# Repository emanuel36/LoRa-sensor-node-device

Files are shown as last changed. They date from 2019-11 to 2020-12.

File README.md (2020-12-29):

  <h3 align="center">A low cost and low power LoRa device sensor-node</h3>

[][release-url]
[][commits-url]
[][stars-url]


 
 <p align="center">
    <br />
    <a href="https://github.com/emanuel36/LoRa-sensor-node-device//tree/master/documentation"><strong>:page_facing_up: Explore the documentation :page_facing_up:</strong></a>
    <br />
    <a href="https://github.com/emanuel36/LoRa-sensor-node-device/issues">:warning: Report or Suggest Something :warning:</a>
  </p>
</p>

<br />
<p align="center">
  <a href="https://github.com/emanuel36/LoRa-sensor-node-device/">
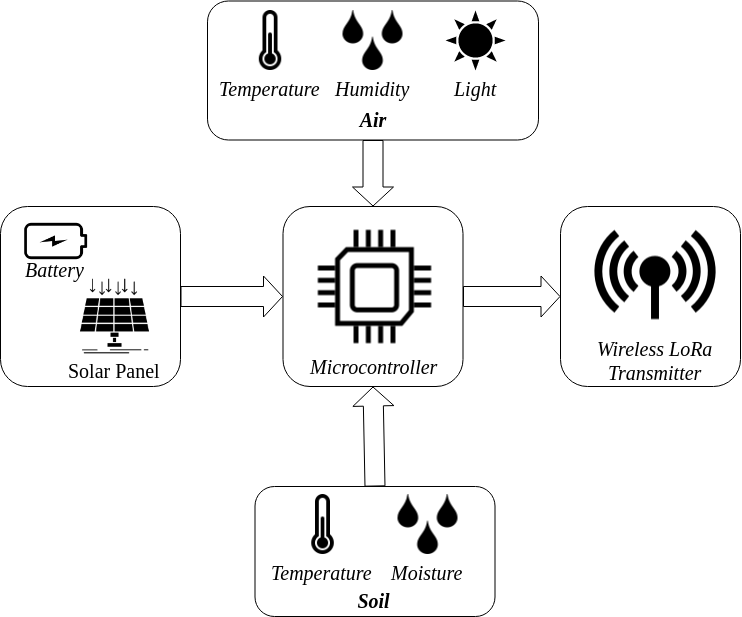
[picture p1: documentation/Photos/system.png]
System Architecture
    
    </a>

## Table of Contents

* [About the Project](#about-the-project)
  * [Built With](#built-with)
* [Detailed description](#detailed-description)
  * [Components Specifications](#components-specifications)
  * [Schematic](#schematic)
  * [Board](#board) 
* [Assembled Board With Components](#assembled-board-with-components)
* [Contact](#contact)

## About The Project

This is a project of a new LoRa device sensor-node. This device is capable of collecting environment data such as temperature, humidity, soil moisture and ambient as well as sending all data to a LoRa gateway from miles away. As can be seen from the [component specifications](#components-specifications) table, this device is very inexpensive, therefore it is suitable equipment to apply to a wireless sensor network in an agricultural field.

More details can be seen in this [publication](https://www.embarcados.com.br/dispositivo-sensor-no-lora-de-baixo-custo-utilizando-energia-solar/) (Portuguese language).

### Built With
* [LoRa](https://lora-alliance.org/)
* [PIC16F18426](https://www.microchip.com/wwwproducts/en/PIC16F18426)
* [MPLAP X IDE](https://www.microchip.com/mplab/mplab-x-ide)

### IDE and Compiler Version
* [MPLAB XC8 v2.10](https://www.microchip.com/development-tools/pic-and-dspic-downloads-archive)
* [MPLAP X IDE v5.30](https://www.microchip.com/development-tools/pic-and-dspic-downloads-archive)

## Detailed Description
This device is designed to work automatically without any human intervention. 

### Microcontroller
The PIC16F18426 is perfect for the project, it's a family of Microchip MCUs intended to sensor node devices.

### Sensors
The device has 4 sensors to measure air temperature, ground temperature, air humidity, soil moisture and sunlight or light levels.

### LoRa Transmitter
The cheap SX1276 transmitter works well at a frequency of 915 MHz, because I'm using it in Brazil.

### Power Supply System
The electrical and power system is designed for decades of operation, with a combination of a large rechargeable battery and a solar-powered recharge system. It is possible to use this device only with solar energy without battery, the battery is only for power supply when there is no sunlight, such as at night and cloudy days.

### Power-Saving Operation Mode
Most of the time the device remains in power save state with all peripherals turned off. When it is necessary to perform some task the system is woken up by an interruption. The data send and transmit period can be set between 5 and 80 minutes, so the system is woken up by a timer interrupt, performs the tasks and returns to power save mode.

### Status LED
The device can signal its current status through a flashing blue LED when it is operating normally and red when something is wrong such as low battery, sensor reading failure or incorrect sensor data such as 80ºC temperature.

### Components specifications

| Component | Description/Documentation | Price (USD) |
|---  |:---:  |---:  |
| Microcontroller | [PIC16F18426](https://www.microchip.com/wwwproducts/en/PIC16F18426) | $1,02 |
| LoRa Transmiter | [SX1276](https://www.semtech.com/products/wireless-rf/lora-transceivers/sx1276) | $4,15 |
| Solar Panel | [Wavgat solar panel 1W/5V](https://pt.aliexpress.com/item/32844672794.html?isOrigTitle=true)  | $1,31 |
| LED | [RGB LED](https://www.sparkfun.com/datasheets/Components/YSL-R596CR3G4B5C-C10.pdf)  | $0,10 |
| Voltage regulator | [LM2596](http://www.ti.com/product/LM2596)  | $0,30 |
| Switch | [DIP Switch 1 way](https://www.we-online.de/katalog/datasheet/418117270901.pdf)  | $0,16 |
| PINS | [Header pin male](https://cdn.sparkfun.com/datasheets/Prototyping/16188.pdf)  | $0,20  |
| MCU Socket | [14-PIN PDIP Socket](https://www.sparkfun.com/products/7939)  | $0,50 |
| 10k Resistors  | [10k Resistors](https://www.circuitspecialists.com/rb10k.html) | $0,12 |
| 4.7k Resistor  | [4.7k Resistors](https://www.circuitspecialists.com/ra4.7k.html) | $0,05 |
| Battery | [Panasonic NCR18650B](https://www.batteryspace.com/prod-specs/NCR18650B.pdf)  | $4,75 |
| Battery Holder  | [BK-18650-PC2](http://www.memoryprotectiondevices.com/datasheets/BK-18650-PC2-datasheet.pdf)  | $0,49 |
| Light Sensor  | [MAX44009](https://www.maximintegrated.com/en/products/interface/sensor-interface/MAX44009.html)  | $1,55 |
| Air Temperature/Humidity Sensor | [Sensirion SHT30](https://www.sensirion.com/en/environmental-sensors/humidity-sensors/digital-humidity-sensors-for-various-applications/) | $1,90 |
| Soil Moisture Sensor  | [Capacitive soil moisture sensor v1.2](https://media.digikey.com/pdf/Data%20Sheets/DFRobot%20PDFs/SEN0193_Web.pdf)  | $0,76 |
| Soil Temperature  | [DS18B20](https://www.maximintegrated.com/en/products/DS18B20)  | $1,00 |
|**Total** |-| **$18,36**|

### Schematic

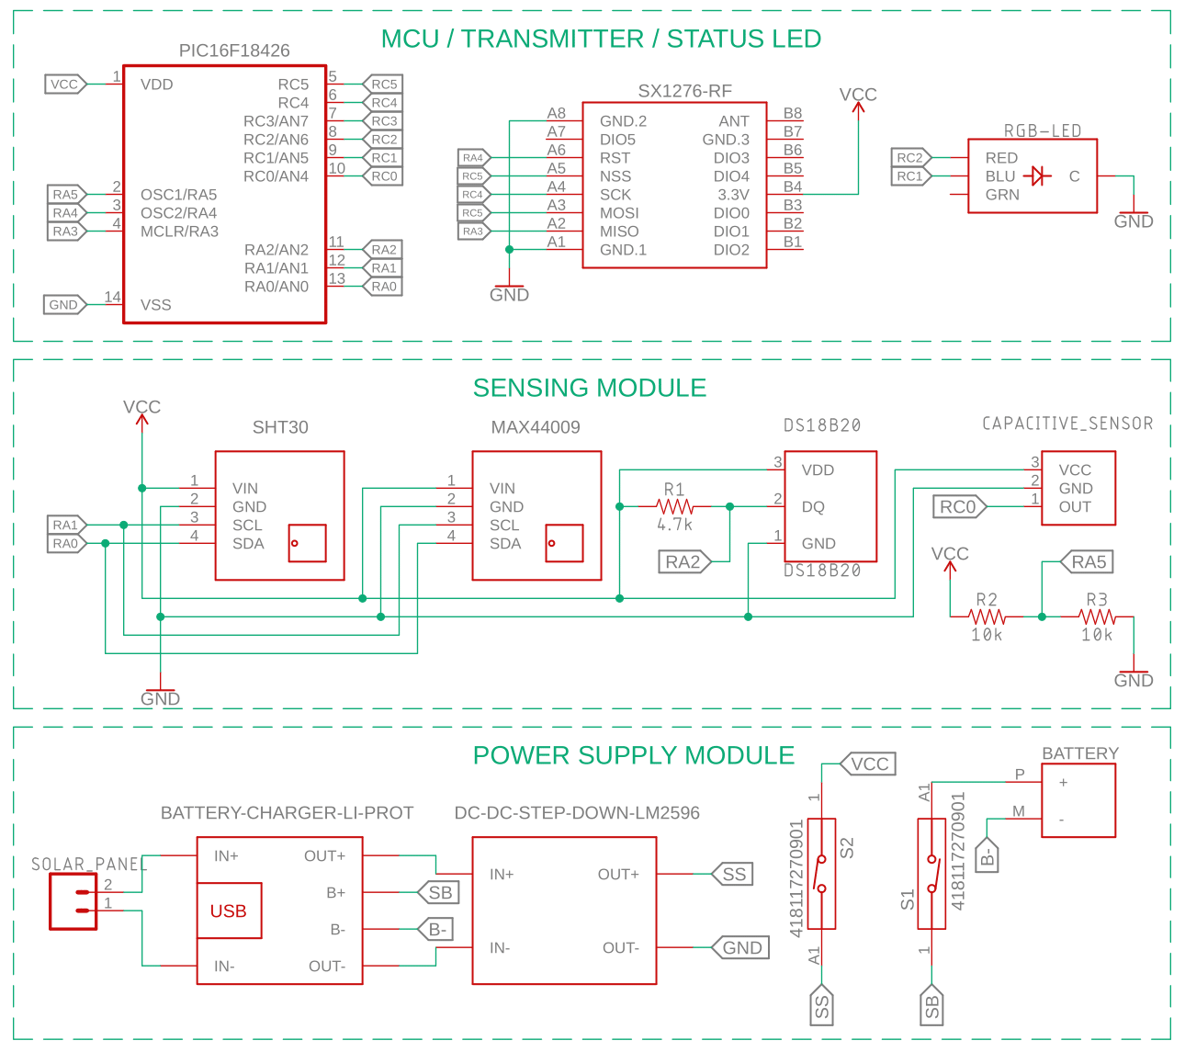
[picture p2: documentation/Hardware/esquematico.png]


### Board

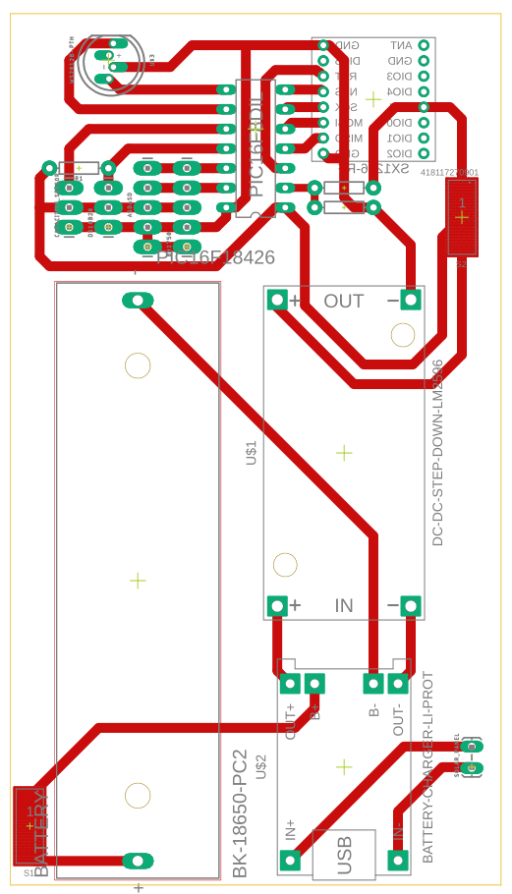
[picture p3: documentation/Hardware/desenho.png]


## Assembled Board With Components

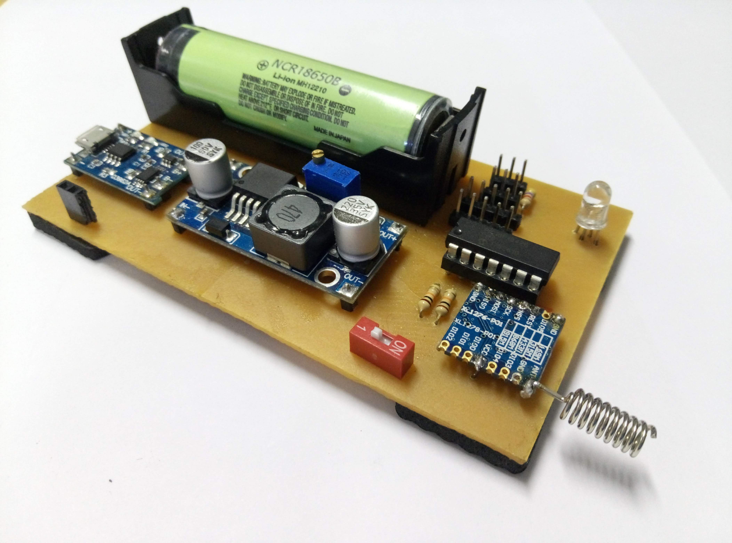
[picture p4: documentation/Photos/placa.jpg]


## System Running

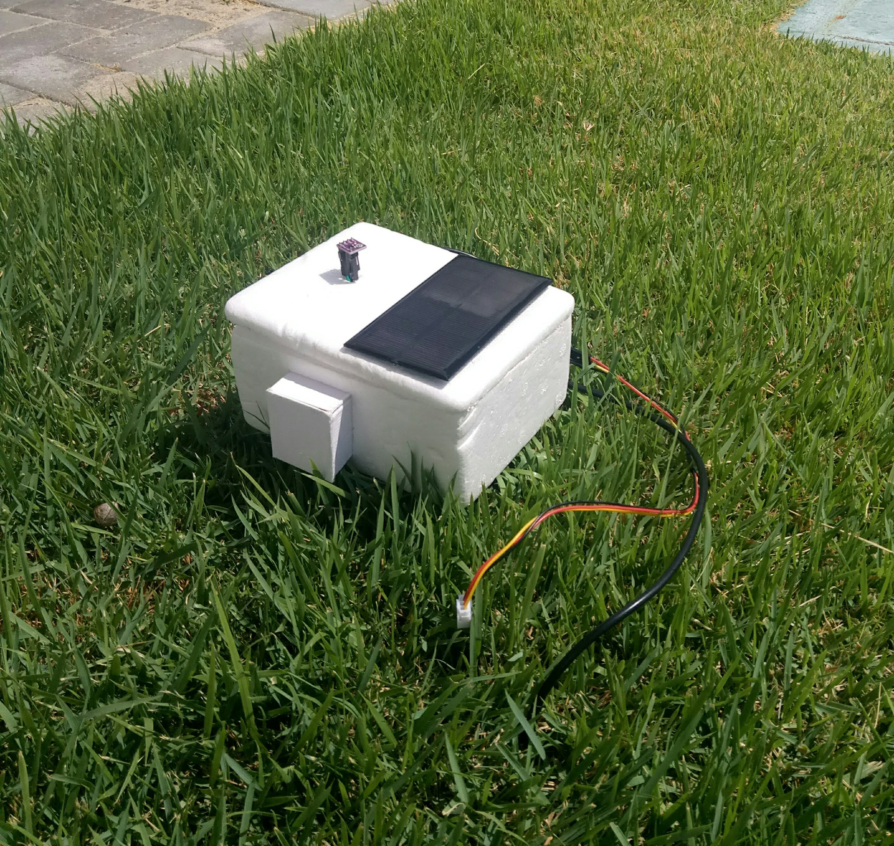
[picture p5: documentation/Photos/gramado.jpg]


## Data collected

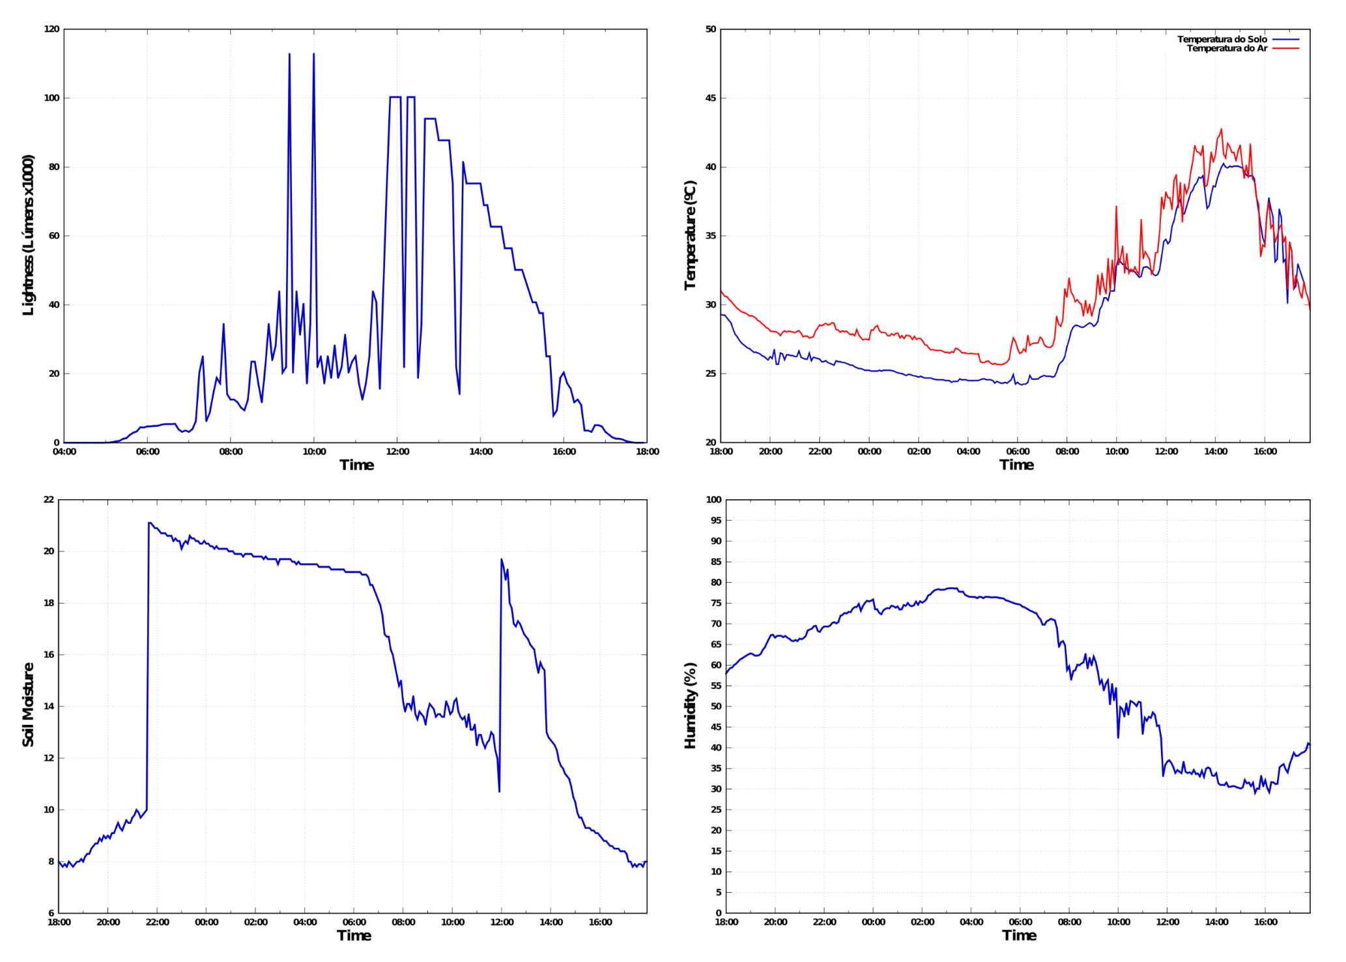
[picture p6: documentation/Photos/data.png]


## Acknowledgements

I would like to thank all the professors I've had since elementary school, this project is the result of a combination of everything you taught me.

The SX1276 LoRa transmitter driver was adapted from https://github.com/sandeepmistry/arduino-LoRa.

[contributors-shield]: https://img.shields.io/github/contributors/emanuel36/LoRa-sensor-node-device?style=for-the-badge
[commits-shield]:https://img.shields.io/github/last-commit/emanuel36/LoRa-sensor-node-device?style=for-the-badge
[commits-url]:https://github.com/emanuel36/LoRa-sensor-node-device/commits/master
[release-shield]:https://img.shields.io/github/v/release/emanuel36/LoRa-sensor-node-device?style=for-the-badge
[release-url]:https://github.com/emanuel36/LoRa-sensor-node-device/releases
[contributors-url]: https://github.com/emanuel36/LoRa-sensor-node-device/graphs/contributors
[stars-shield]: https://img.shields.io/github/stars/emanuel36/LoRa-sensor-node-device?color=183c0d&style=for-the-badge
[stars-url]: https://github.com/emanuel36/LoRa-sensor-node-device/stargazers
[language-shield]: https://img.shields.io/github/languages/top/emanuel36/LoRa-sensor-node-device?color=191970&style=for-the-badge
[language-url]: https://github.com/emanuel36/LoRa-sensor-node-device/search?l=c
[size-shield]: https://img.shields.io/github/languages/code-size/emanuel36/LoRa-sensor-node-device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
[issues-shield]: https://img.shields.io/github/issues/emanuel36/LoRa-sensor-node-device?style=for-the-badge
[issues-url]:https://github.com/emanuel36/LoRa-sensor-node-device/issues
[linkedin-shield]: https://img.shields.io/badge/-LinkedIn-blue?style=for-the-badge
[linkedin-url]: https://www.linkedin.com/in/emanuel36/en

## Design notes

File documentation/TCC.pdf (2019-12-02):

UNIVERSIDADE FEDERAL DO CEARÁ

CAMPUS DE QUIXADÁ

CURSO DE GRADUAÇÃO EM ENGENHARIA DE COMPUTAÇÃO

EMANUEL ANGELIM PEREIRA

IMPLEMENTAÇÃO DE UM DISPOSITIVO PARA REDE DE SENSORES SEM FIO

LORA ® UTILIZANDO ENERGIA SOLAR

QUIXADÁ - CEARÁ

2019

EMANUEL ANGELIM PEREIRA

IMPLEMENTAÇÃO DE UM DISPOSITIVO PARA REDE DE SENSORES SEM FIO LORA

® UTILIZANDO ENERGIA SOLAR

Trabalho de Conclusão de Curso apresentado ao Curso de Graduação em Engenharia de Computação do Campus de Quixadá da Universidade Federal do Ceará, como requisito parcial à obtenção do grau de bacharel em Engenharia de Computação.

Orientador: Prof. | Me. | Francisco Helder
Candido dos Santos Filho.

QUIXADÁ - CEARÁ

EMANUEL ANGELIM PEREIRA

IMPLEMENTAÇÃO DE UM DISPOSITIVO PARA REDE DE SENSORES SEM FIO LORA

® UTILIZANDO ENERGIA SOLAR

Trabalho de Conclusão de Curso apresentado ao Curso de Graduação em Engenharia de Computação do Campus de Quixadá da Universidade Federal do Ceará, como requisito parcial à obtenção do grau de bacharel em Engenharia de Computação.

Aprovada em:

BANCA EXAMINADORA

Prof. Me. Francisco Helder Candido dos Santos Filho. (Orientador)
Universidade Federal do Ceará (UFC)

Prof. Dr. André Ribeiro Braga Universidade Federal do Ceará (UFC)

Prof. Dr. Elvis Miguel Galeas Stancanelli Universidade Federal do Ceará (UFC)

Dedico esta monografia aos meus pais e avós,

pilares da minha formação como ser humano.

Palavras não são suficientes para demonstrar a

minha gratidão por sua dedicação, apoio, amor

e confiança em mim.

AGRADECIMENTOS

A minha mãe Edisônia, seus exemplos de vida, cuidado e carinho foi o que deu

sentido para continuar crescendo na vida e superando todos os desafios.

Ao meu Pai Marcelino, seu enorme apoio, presença e positividade significou espe-

rança, segurança e certeza de que não estou sozinho nessa caminhada.

Aos meus avós Carmelita, Maria e Mauro, que sempre sonharam em me ver formado

e se preocuparam comigo apoiando e confiando em mim.

Aos meus irmãos, tios e primos, por me apoiarem e estarem próximo de mim.

Ao Prof. Francisco Helder Candido dos Santos Filho por me orientar no meu

Trabalho de Conclusão de Curso.

Aos professores, por me repassar o seu conhecimento técnico e experiências de vida,

vocês foram essenciais nessa jornada.

Ao Prof. Alisson Barbosa de Souza por apoiar e sugerir o tema principal deste

trabalho.

A minha prima Débora Ferreira, por estar sempre comigo e por revisar a ortografia

do texto deste trabalho.

Ao Robert Cabral, pelo apoio durante toda execução do trabalho.

Ao meu amigo Túlio, por revisar todo o trabalho.

“O impossível existe até que alguém duvide dele

e prove o contrário.”

(Albert Einstein)

RESUMO

As Redes de Sensores sem Fio estão sendo utilizadas cada vez mais em diversos tipos de

sistemas voltados para monitoramento. Entre os protocolos de comunicação utilizados por esses

sistemas, o LoRa ® vem ganhando destaque devido suportar transmissões em distâncias muito

maiores que os demais, demandando pouca energia. Utilizar fontes de energias renováveis

como energia solar, também tem sido uma tendência, com o intuito principal de não agredir o

meio ambiente bem como tornar a aplicação do sistema mais barata a longo prazo. O presente

trabalho propõe o desenvolvimento de um dispositivo para atuar em uma rede de sensores sem

fio utilizando o protocolo LoRa ®, assim como energia solar como fonte de alimentação do

sistema. O dispositivo deverá dispor de alguns sensores de forma que o sistema seja voltado para

aplicações no campo, tornando processos como agricultura mais eficientes. Entre os resultados

há o detalhamento do processo de seleção de cada componente do dispositivo assim como

o comportamento de cada sensor durante um período de 24 horas de leituras e transmissões.

Além disso é apresentado as funcionalidades do dispositivo e as principais configurações dos

periféricos e módulos do microcontrolador.

Palavras-chave: LoRa. Microcontrolador. Redes de Sensores sem Fio. Sensor.

ABSTRACT

Wireless Sensor Networks are increasingly being used in various types of systems focused

on monitoring. Among the communication protocols used by these systems, LoRa ® has

gained prominence because it supports transmission over much longer distances than the others,

requiring little energy. Use renewable energy sources as energy solar, has also been a trend,

with the main purpose of not harming the environment as well as making the system application

cheaper in the long run. The present thesis proposes the development of a device to operate

in a wireless sensors network using LoRa ® protocol, as well as solar energy as a source of

system power. The device should have some sensors in such a way that the system be focused

on agriculture applications, improving the process. The results include a detailed process for

selecting each device component as well as the behavior of each sensor over a 24 hours of reading

and transmissing period. In addition, the device main features are shown as configurations of

microcontroller peripherals and modules.

Keywords: LoRa. Microcontroller. Wireless Sensor Network. Sensor.

LISTA DE FIGURAS

Figura 7 – Diagrama de bloco de um nó genérico de uma rede de sensores sem fio . . . | 29
Figura 8 – Corrente de alimentação dos transmissores LoRa ® SX1276 e RN2903 . . . | 36

LISTA DE TABELAS

LISTA DE QUADROS

LISTA DE CÓDIGOS-FONTE

Código-fonte 3 – Estrutura que contém os perídos configuráveis do temporizador . . . 44

LISTA DE SÍMBOLOS

km | Distância
km² | Área
kHz | Frequência
MHz | Frequência
GHz | Frequência
dBm | Potência
V | Tensão Elétrica
mA | Corrente elétrica
µA | Corrente elétrica
kΩ | Resistência Elétrica
MHz | Frequência
◦C | Temperatura
Lux | Luminosidade

SUMÁRIO

### 2.1 Development of Plough-able RFID Sensor Network Systems for Preci-

### 2.2 Design and implementation of WSN for precision agriculture in white

### 2.3 Monitoring device for culture substrate growth parameters for precision

4.2 | Definir protocolo de comunicação que será suportado pelo sistema . . . | 32

### 1 INTRODUÇÃO

Entre os maiores problemas e desafios enfrentados atualmente pela humanidade,

incluem-se: a falta de água própria para consumo, mudanças drásticas no clima e produção de

comida insuficiente, principalmente em regiões mais pobres (ILIE-ABLACHIM et al., 2016).

Na região Nordeste do Brasil muitos agricultores são bastantes limitados em relação ao período

do ano em que podem realizar o plantio em médias e grandes proporções, pois além da taxa

de precipitação ser muito baixa, toda essa precipitação ocorre durante um único e pequeno

período do ano. Dessa forma, durante o período de seca, o agricultor não consegue exercer seu

trabalho na lavoura pois a quantidade de água necessária para irrigar a plantação com os métodos

tradicionais é insuficiente.

A prática da agricultura convencional, que utiliza métodos tradicionais, é bastante

ineficiente, pois demanda uma elevada quantidade de recursos, incluindo água. A agricultura

no Brasil é responsável pelo maior consumo de água, cerca de 72% do consumo total (ALVES,

2015). Contudo, a produção pode ser otimizada de forma muito significativa, ao adotar técnicas

avançadas na agricultura. A aplicação da tecnologia no campo pode envolver conceitos que

surgiram e estão evoluindo ao longo dos últimos anos: Internet of Things (IoT), Wireless Sensor

Network (WSN) e Precision Agriculture (PA).

O conceito IoT se refere a ter diversos aparelhos conectados na Internet, sendo

acessíveis ou controláveis a partir de qualquer lugar e dispositivo que possua conexão à Internet.

Os sistemas WSN utilizam ondas de rádio para transmitir os pacotes coletados pelos dispositivos

finais, que por sua vez, são formados basicamente de sensores, microcontrolador, transmissor e

sistema de alimentação. E por fim, a PA consiste em utilizar tecnologia avançada para aumentar

a quantidade e a qualidade da produção utilizando menos recursos naturais.

Visando a problemática apresentada, o presente trabalho propõe uma solução que

utilizará os conceitos citados anteriormente: WSN, IoT e PA. O trabalho tem foco no desenvol-

vimento do projeto de um dispositivo que atuará como um nó em uma WSN. Este dispositivo

deverá ser capaz de realizar medidas de fatores ambientais, que influenciam na atividade da

agricultura. Além de processar os dados obtidos, o dispositivo final deverá suportar o envio das

informações para uma base de dados, que poderá reunir as informações atualizadas de todos os

nós conectados na rede. Com todos os dados reunidos e acessíveis, um sistema poderá acessar

esses dados que interferem na plantação, como umidade, temperatura e radiação solar. A partir

desses dados, sistemas de irrigação poderão controlar a quantidade de água em cada região do campo de forma muito precisa, e em ambientes mais controláveis, poderá ajustar os níveis de

luminosidade e umidade do ar de acordo com as necessidades do tipo de plantação.

Os trabalhos de Wang et al. (2014), Juan et al. (2017) e Ilie-Ablachim et al. (2016)

apresentam soluções similares, contudo, a maioria é voltada para um tipo específico de local

ou de plantação, pois possuem alguns tipos de limitações, tais como alcance de transmissão,

alto consumo de energia, baixa autonomia e baixa disponibilidade. O dispositivo proposto neste

trabalho deverá possuir alto nível de automatização e autonomia, de modo que seja possível a

aplicação do mesmo modelo de dispositivo em redes de sensores sem fio situadas em diversos

tipos de plantações e tipos de ambientes.

### 1.1 OBJETIVOS

### 1.1.1 Objetivo geral

Desenvolver um dispositivo para ser utilizado como um nó em uma WSN, de forma

que este dispositivo seja capaz de operar em conjunto com outros sistemas em busca de tornar o

processo da agricultura mais eficiente e econômico.

### 1.1.2 Objetivos Específicos

- Utilizar um protocolo de comunicação que suporte um transmissor de longo alcance, baixo

consumo de energia e fácil escalabilidade dentro da rede.

- Selecionar os componentes mais adequados ao projeto, levando em conta suas característi-

cas individualmente.

- Implementar um sistema fotovoltaico para alimentar o dispositivo e recarregar a bateria.
- Aplicar técnicas de minimização de consumo de energia, em busca de obter alta durabili-

dade e disponibilidade.

- Montar um protótipo com todos os componentes do sistema, submetê-lo a testes e analisar

os resultados obtidos.

### 2 TRABALHOS RELACIONADOS

Nesta seção serão apresentados três trabalhos relacionados, destacando seus pontos

fortes e pontos negativos além das semelhanças e diferenças com o dispositivo proposto por este

trabalho.

### 2.1 Development of Plough-able RFID Sensor Network Systems for Precision Agricul-

ture

A ideia geral do trabalho desenvolvido por Wang et al. (2014) é implementar um

dispositivo com sensores, microcontrolador, transmissor e antena. Sua proposta consiste em

espalhar vários dispositivos em um campo, que devem ficar sob o solo, em uma profundidade

adequada para realizar leituras de parâmetros e enviar os dados coletados para um instrumento

leitor que se posicionará sobre o solo.

O diferencial desse dispositivo é o protocolo de comunicação: o Radio Frequency

Identification (RFID). O sistema RFID passivo, que é o utilizado neste projeto, se destaca por

não necessitar de alimentação contínua. Isso ocorre devido ao transmissor que se localiza no

dispositivo final, que além de enviar dados para o leitor, alimenta o sistema através da corrente

induzida pelo campo magnético gerado pelo leitor (TANIM, 2016). Dessa forma, para coletar

informações de um determinado dispositivo, um equipamento leitor RFID deve ser posicionado

sobre a região do solo que se encontra o dispositivo, logo, o sistema será alimentado pelo campo

magnético do leitor, que por sua vez receberá os dados de leitura enviados pelo transmissor.

A grande vantagem desse sistema é o fato do seu módulo de alimentação não interferir

na sua a autonomia. Outra grande vantagem é o custo individual de cada dispositivo, pois o

sistema RFID passivo é muito barato (LI et al., 2018). Porém a necessidade de um leitor para

realizar as medições torna o sistema mais dependente da ação humana e menos automatizado.

Além disso, em plantações mais altas, o posicionamento do leitor seria um desafio, o que limita

a aplicação do modelo em plantações baixas.

Apesar de ter um objetivo em comum com o projeto proposto neste trabalho, existem

diversas diferenças entre os dois dispositivos. De uma forma geral, o modelo desenvolvido por

Wang et al. (2014) é voltado para coletar informações somente do solo, enquanto o proposto

neste trabalho será capaz de ler dados do solo e do ar. Outra grande diferença é o modo de

transmissão de dados, em Wang et al. (2014) é necessária atuação humana, no trabalho proposto, o processo é totalmente automatizado.

### 2.2 Design and implementation of WSN for precision agriculture in white cabbage crops

No trabalho de Juan et al. (2017), foi implementado um dispositivo chamado Smart-

Node, que possui três sensores que são responsáveis por coletar informações sobre luminosidade,

temperatura do ar e umidade do solo. O objetivo principal do seu trabalho é enviar informações

ambientais do local de uma plantação de repolho para um servidor localizado a uma distância de

aproximadamente 2 km do local onde os dispositivos estão instalados.

O sistema de alimentação desse dispositivo merece destaque, pois utiliza uma bateria

recarregável, e através de uma placa solar e um circuito de carregamento, essa bateria é recar-

regada utilizando energia renovável. Esse sistema gera economia, pois a bateria recarregável

dura muito mais tempo que uma comum, gera autonomia devido a desnecessidade de remover as

baterias para recarregar e não menos importante, minimiza o impacto ambiental já que evita o

descarte excessivo de baterias.

Entretanto, Juan et al. (2017) optou por utilizar o protocolo de comunicação Zigbee,

que transmite dados na frequência 2,4 GHz (PAN et al., 2018), um dos motivos que torna o

alcance de comunicação baixo. Além disso, o protocolo Zigbee utiliza o método de múltiplos

saltos, dessa forma outros nós presentes na rede precisam rotear pacotes de outros nós próximos

fisicamente (MEERA et al., 2015), o que aumenta a complexidade da rede e causa dependências.

Em outras palavras, caso um nó essencial no roteamento de pacotes fique indisponível, parte dos

nós perderão a conexão com a rede, comprometendo todo o sistema. Outro impacto negativo

causado pelo protocolo baseado em múltiplos saltos é o acréscimo do tempo ativo dos dispositivos,

visto que terão de ficar ativos sempre que tiverem de enviar seus próprios dados ou rotear pacotes

de outros nós, o que afeta diretamente o consumo de energia.

O objetivo final da pesquisa de Juan et al. (2017) possui grandes semelhanças com o

objetivo final do trabalho proposto. Ambos tem intenção de otimizar o processo da agricultura

através da coleta e envio de informações ambientais, além de utilizarem energia renovável como

fonte de alimentação. Contudo, o dispositivo de Juan et al. (2017) é voltado para plantações

rasteiras, como as de repolho, enquanto o dispositivo proposto poderá ser aplicado em diversos

tipos de plantações. Além disso, o protocolo de comunicação do SmartNode limita bastante a

distância entre os dispositivos da rede, portanto, a implementação de um sistema em um campo

extenso utilizando esse modelo terá um alto custo, devido a quantidade de dispositivos necessária.

### 2.3 Monitoring device for culture substrate growth parameters for precision agriculture

No trabalho desenvolvido por Ilie-Ablachim et al. (2016) foi projetado um dispositivo

nomeado MoniSen. O MoniSen é um modelo de dispositivo final que pode ser aplicado em uma

rede de sensores sem fio de longo alcance, pois utiliza o protocolo de comunicação LoRa ® que

tem como características principais o longo alcance de transmissão e o baixo consumo de energia

(DEVALAL; KARTHIKEYAN, 2018).

O dispositivo em si é composto por alguns sensores que são responsáveis por medir

os seguintes parâmetros: luminosidade, temperatura do solo, temperatura do ar, umidade do

solo e umidade do ar. Os modelos de sensores selecionados para o projeto não são os melhores,

pois existem opções mais precisas, econômicas e com custo de aquisição similar. Além desses

sensores, o MoniSen possui o transmissor LoRa ® e um microcontrolador de baixo processamento

e consumo. As baterias de lítio que o alimenta tem capacidade de 2400 mAh, dando uma

autonomia de aproximadamente 6 meses.

O projeto desenvolvido por Ilie-Ablachim et al. (2016) é similar ao projeto proposto

neste trabalho, pois ambos utilizam sensores para medir parâmetros do ar e do solo do ambiente,

além de possuírem suporte a transmissão de longo alcance. As diferenças mais impactantes entre

os dois modelos são a qualidade dos sensores e o sistema de alimentação, tendo em vista que

o modelo proposto neste trabalho utiliza energia solar para recarregar a bateria. Uma grande

vantagem de implementar um sistema de alimentação mais robusto é a capacidade de realizar

leituras e envios dos dados com uma maior frequência, o que torna possível uma análise mais

detalhada sobre o comportamento do ambiente.

### 2.4 Análise comparativa

No Quadro 1, há a comparação entre os dispositivos projetados nos trabalhos rela-

cionados e o dispositivo projetado neste trabalho, mostrando as funcionalidades que cada um

possui.

Quadro 1 – Comparação entre os trabalhos relacionados e o proposto
Funcionalidade | Modelos de dispositivo
2.1 Sistema RFID | 2.3 MoniSen | 2.2 SmartNode | Trabalho proposto
Suporte à comunicação de longo alcance | ✗ | ✓ | ✗ | ✓
Autonomia elétrica ilimitada | ✓ | ✗ | ✓ | ✓
Sistema fotovoltaico de alimentação | Não se aplica | ✗ | ✓ | ✓
Ecologicamente sustentável | ✓ | ✗ | ✓ | ✓
Sensor de umidade do ar | ✗ | ✓ | ✓ | ✓
Sensor de temperatura do ar | ✗ | ✓ | ✓ | ✓
Sensor de umidade do solo | ✓ | ✓ | ✓ | ✓
Sensor de temperatura do solo | ✓ | ✓ | ✓ | ✓
Sensor de luminosidade | ✗ | ✓ | ✗ | ✓

Fonte: Elaborado pelo autor.

Como pode ser observado, o sistema proposto por Juan et al. (2017) é o que mais

se aproxima do sistema proposto nesse trabalho, contudo não suporta comunicação de longo

alcance, nem é capaz de medir os níveis de luminosidade do ambiente. O fato do dispositivo

proposto suportar todas essas funcionalidades, o torna capaz de atuar em diferentes tipos de

ambientes e plantações.

### 3 FUNDAMENTAÇÃO TEÓRICA

### 3.1 Sensores

Um sensor é um dispositivo capaz de responder a um estímulo físico ou químico

e converter em outra grandeza física, em busca de obter medidas ou realizar monitoramento

(BALBINOT; BRUSAMARELLO, 2011). Os sensores possuem um componente denominado

transdutor, que é responsável por converter o sinal proveniente da interação entre o sensor e o

ambiente físico em um sinal elétrico analógico ou digital. A partir do sinal elétrico, um sistema

pode realizar a leitura do sensor a fim de obter a informação fornecida pelo mesmo (BOARD et

al., 1997). A Figura 1 fornece uma visão geral da estrutura básica de um sensor genérico.

Figura 1 – Modelo genérico de um sensor

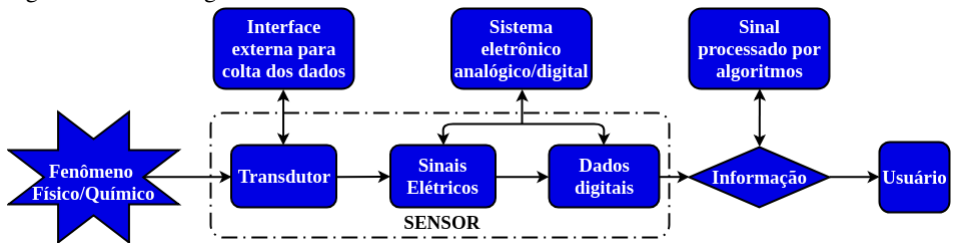
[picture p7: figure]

Fonte: Adaptado de Board et al. (1997)

Os sensores são bastante utilizados na indústria, e tem uma grande contribuição nos

recentes avanços tecnológicos, pois os sistemas de carros, aviões, satélites, computadores, e até

mesmo de aparelhos mais simples como condicionador de ar, possuem sistemas de controle.

Os sensores são componentes cruciais para o funcionamento desse tipo de sistema, visto que a

atuação e comportamento do sistema depende do estado do ambiente, que é obtido a partir da

leitura dos seus sensores. A Figura 2 mostra alguns modelos de sensores comumente utilizados

em projetos de sistemas de controle e monitoramento.

Alguns fatores ambientais interferem diretamente no desenvolvimento da plantação,

tais como temperatura, umidade e luminosidade. Em busca de realizar medições automatizadas

desses fatores, o dispositivo proposto neste trabalho terá alguns sensores como componentes

cruciais.

Figura 2 – Modelos de sensores

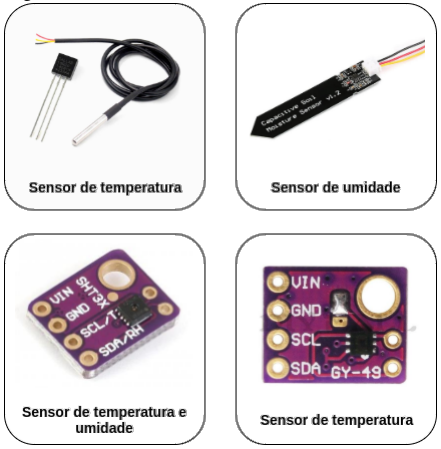
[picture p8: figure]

Fonte: Elaborado pelo autor.

### 3.2 Rede de sensores sem fio

Diferentemente de uma rede cabeada, as redes sem fio proporcionam uma grande

mobilidade dos dispositivos nela conectados. Ao invés de se propagar através de sinais elétricos

em cabos, os dados trocados entre dispositivos dentro da rede, se propagam por meio de ondas

de rádio. O uso de uma rede sem fio permite evitar meios dispendiosos de instalar cabos para

conectar dispositivos em diferentes locais (TIWARI et al., 2015).

De acordo com a autora Forster (2016) um sistema WSN é um termo que especifica

um conjunto de computadores com o objetivo principal de medir alguma propriedade física do

ambiente como temperatura, umidade ou vibração. Um sistema WSN é composto por vários

dispositivos com sensores acoplados, que realizam a função de um nó na rede, além disso,

esses dispositivos são conectados em uma rede através de tecnologias de comunicação sem fio.

Tipicamente, há um dispositivo especial na rede, que é chamado de estação base, o qual conecta

a rede de sensores ao mundo exterior.

Figura 3 – Exemplo de rede Rede de Sensores sem Fio

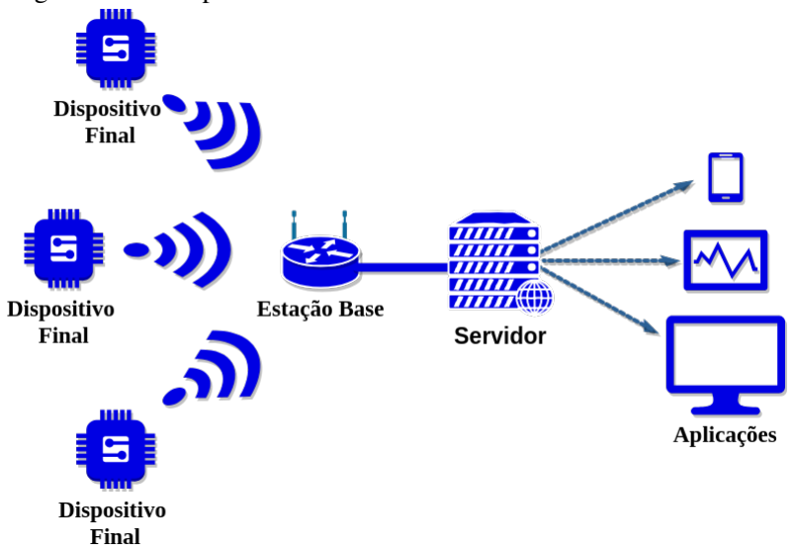
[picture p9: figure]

Fonte: Elaborado pelo autor.

A Figura 3 dá uma visão geral da estrutura básica de uma rede WSN. Como pode

ser observado, cada dispositivo final é capaz de enviar e receber da estação base, utilizando um

protocolo de comunicação sem fio. A estação base encaminha esses dados para um servidor, que

disponibiliza os dados para os usuários, através de aplicações.

### 3.2.1 Desafios em redes de sensores sem fio

O autor Tiwari et al. (2015) lista alguns desafios relacionados ao desenvolvimento

de WSN.

1. Segurança: Os pacotes trocados entre os nós da rede podem ser interceptados, já que são

transmitidos através de ondas de rádio.

2. Localização: A localização geográfica dos nós além de afetar o consumo de energia,

interfere na arquitetura de rede de protocolos de roteamento indireto.

3. Consumo de energia e autonomia: Em diversos sistemas de WSN os nós são posiciona-

dos em áreas de difícil acesso, dessa forma a necessidade de trocas frequentes de bateria

pode não ser viável, logo o consumo do dispositivo deve se minimizado ao máximo.

### 3.2.2 Protocolos mais utilizados em redes de sensores sem fio

3.2.2.1 LoRa ®

Segundo o trabalho de Devalal e Karthikeyan (2018), o protocolo LoRa ® é voltado

para sistemas que utilizam baterias e precisam transmitir pequena quantidade de dados em

intervalos curtos e em longas distâncias. Os transmissores LoRa ® utilizam faixas de frequências

que podem variar de acordo com a região. A Tabela 1 especifica as faixas de frequências

utilizadas em diferentes regiões do globo terrestre.

Tabela 1 – Banda de frequência por região

Região | Banda
Europa | 868 e 433 MHz
América do norte e Brasil | 915 MHz
Ásia | 430 MHz

Fonte: Adaptado de LoRa Alliance Technical Commitee (2017)

A arquitetura da rede LoRa ® é baseada na topologia estrela, na qual um dispositivo

central, o roteador recebe e envia dados para os dispositivos finais da rede. O roteador deve ser

conectado à Internet através de Wi-Fi, Ethernet, rede de celular ou satélite, visando enviar os

dados recebidos dos dispositivos finais para uma base de dados. Em uma rede LoRa ® pode

existir mais de um roteador, caso apenas um não seja suficiente para cobrir uma determinada

área. Esses dispositivos possuem um alcance muito grande, os mais robustos conseguem cobrir

uma área de até 100 km²
(DEVALAL; KARTHIKEYAN, 2018).
Region | Frequency
Europe | 868/433 MHz
America | 915 MHz
Asia | 430 MHz

3.2.2.2 Zigbee

O protocolo Zigbee é voltado para aplicações de curto e médio alcance que variam

entre 10 e 100 metros de distância (FARAHANI, 2009). Os dispositivos que compõe uma

rede Zigbee são os dispositivos finais, os roteadores e o coordenador de rede. De acordo com

a organização desses dispositivos na rede, o protocolo pode assumir três tipos diferentes de

topologias, que podem ser observadas na Figura 4.

- Estrela

Na topologia estrela, o coordenador pode se comunicar com qualquer outro dispositivo

conectado na rede.

- Malha

Na topologia malha, um dispositivo pode se comunicar com qualquer outro na rede,

desde que a distância entre os dois seja suficientemente pequena a ponto de permitir troca

de mensagens. Essa configuração permite que existam múltiplos caminhos ligando um

dispositivo aos outros na rede.

- Árvore

Essa topologia se assemelha à topologia malha, entretanto nesse modo de operação os

dispositivos finais não realizam roteamento de pacotes, apenas o roteadores e o coordenador

assumem esse papel.

Figura 4 – Topologias de uma rede Zigbee

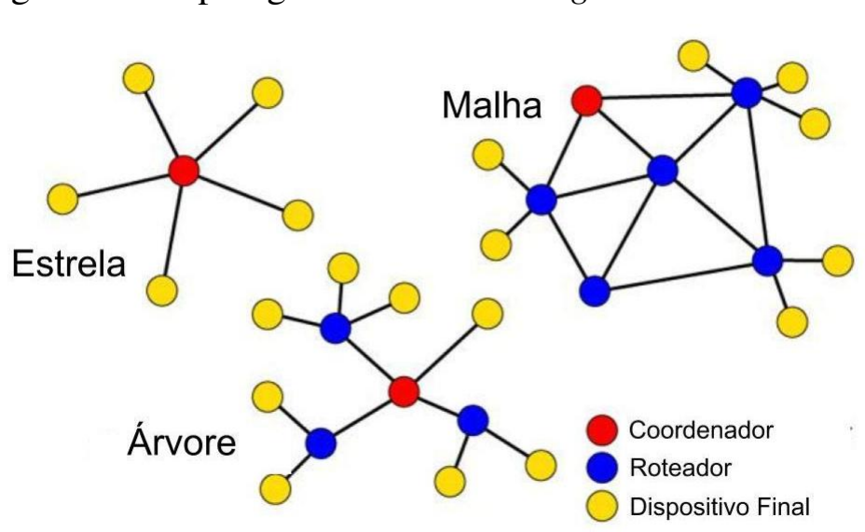
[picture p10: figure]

Fonte: Adaptado de Pathak et al. (2015)

As aplicações mais comuns que utilizam o Zigbee como protocolo de transmissão

são em automação residencial e comercial, controle industrial, monitoramento de parâmetros

relacionados à saúde pessoal, entre outras (TOMAR, 2011).

3.2.2.3 Wi-Fi

O protocolo IEEE 802.11, popularmente conhecido como Wi-Fi também pode ser

aplicado em WSN. Contudo, este protocolo não foi desenvolvido especificamente para este fim,

logo pode ser inviável utilizá-lo, dependendo dos requisitos do sistema.

Este protocolo possui dois modos de operação: infraestruturado e ad hoc, como

pode ser observado na Figura 5. O modo infraestruturado consiste em uma topologia estrela, na

qual um dispositivo central se conecta com todos os outros dispositivos, já no modo ad hoc, os

dispositivos se comunicam diretamente entre si, com diferentes possibilidades de roteamento das

mensagens enviadas (ANASTASI et al., 2003).

Figura 5 – Modos de operação da rede Wi-Fi

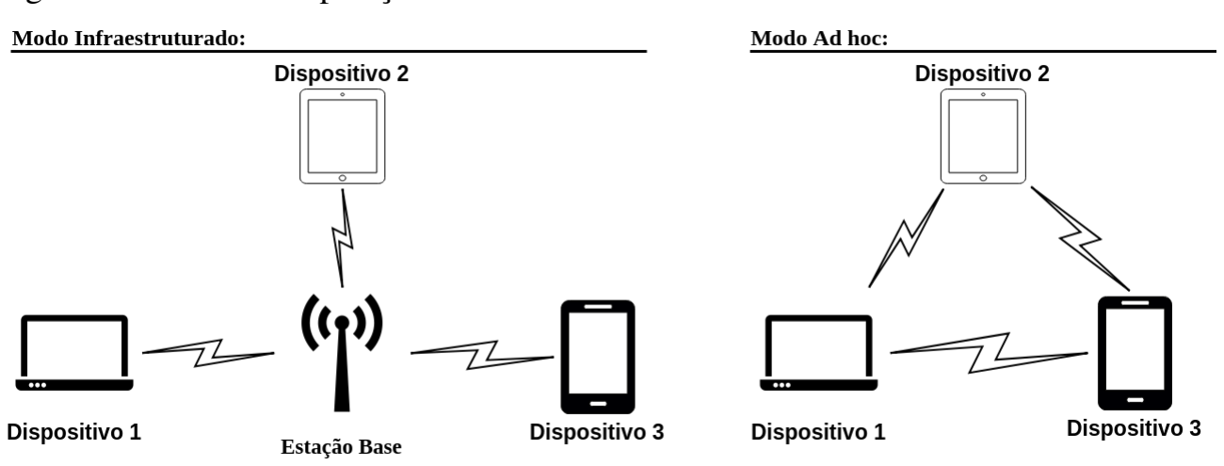
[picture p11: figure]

Fonte: Elaborado pelo autor.

O grande desafio de utilizar Wi-Fi em redes de sensores é o consumo de energia

do transmissor. Um transmissor Wi-Fi muito comum em projetos, o ESP-01 (AI-THINKER,

2015), possui um consumo muito maior, se comparado com um transmissor LoRa ® SX1276

(SEMTECH, 2015), como pode ser observado no gráfico da Figura 6.

### 3.2.3 Estrutura básica de um nó em uma rede de sensores sem fio

Cada nó de uma WSN é composto basicamente por microcontrolador, sensores,

bateria e transmissor, como demonstra a Figura 7. Com a possibilidade de aplicar sistemas

de WSN em grandes áreas para monitoramento, cada nó deve ser barato. Em busca de tornar

esses dispositivos baratos, os recursos presentes em cada dispositivo são altamente limitados, em

relação a processamento, energia e componentes de hardware (FORSTER, 2016) .

O propósito principal deste trabalho é desenvolver um modelo de nó voltado para

Figura 6 – Consumo dos transmissores LoRa ® SX1276 e Wi-Fi ESP-01

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
8 | 10 | 12 | 14 | 16

Consumo (mA)

Potência (dBm)

SX1276
ESP−01

Fonte: Elaborado pelo autor.

Figura 7 – Diagrama de bloco de um nó genérico de uma rede de sensores sem fio

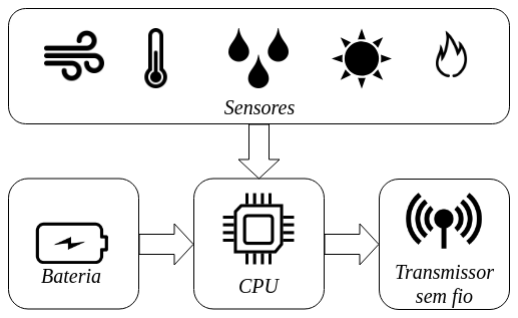
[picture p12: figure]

Fonte: Elaborado pelo autor.

monitoramento no setor da agricultura, em busca de torná-la mais eficiente e econômica.

Quadro 2 – Aplicações de redes de sensores sem fio
Área | Aplicação
Industrial | Monitoramento e controle de equipamentos
Aeroportos | Sistema de etiquetas inteligente em malas
Comercial | Gerência de estoque e check out
Situações emergenciais | Detectores de incêndio e vazamento de gás
Militar | Detectação de movimentação inimiga
Fonte: Adaptado de García-Hernández et al. (2007)

O Quadro 2 mostra algumas das diversas outras aplicações de sistemas WSN.

### 3.3 Agricultura de Precisão

De acordo com o autor Davis et al. (1998), a PA combina as novas tecnologias da

era da informação com a agricultura industrializada. Um sistema baseado em PA visa descobrir

as necessidades reais de insumo em pequenas áreas dentro de um campo agrícola, de modo

que a aplicação desses recursos não seja excedente ou insuficiente, mas seja suficiente para o

desenvolvimento da plantação. Esse propósito não é novo, entretanto as tecnologias recentes

permitem o avanço na pesquisa e desenvolvimento de sistemas nessa área.

O fator chave para a PA ser mais eficiente que a agricultura tradicional é a informação.

A forma com que a informação é coletada é essencial para a eficiência dos sistemas de PA, pois

nesses sistemas, o campo agrícola é dividido em pequenas áreas, visto que cada área pode ter

necessidades diferentes de insumo, de acordo com o relevo, tipo de solo, tempo de exposição

ao sol, temperatura e umidade. Em um terreno muito grande, essa necessidade de divisão em

pequenas áreas fica mais visível, pois as características ambientais podem variar muito entre

regiões situadas a algumas centenas de metros entre si (DAVIS et al., 1998).

Baseado nas condições ambientais de pequenas áreas divididas dentro do campo

agrícola, a aplicação de insumos pode ser precisamente controlada em cada uma dessas áreas de

forma independente, o que gera uma série de benefícios. Entre esses benefícios, destaca-se a

minimização do impacto ambiental, já que a agricultura é responsável por grande consumo de

água, e em diversos lugares do mundo é enfrentado escassez de água (PEREIRA et al., 2002).

Além da vantagem ambiental, há também a vantagem econômica, pois os produtores podem

produzir mais, com menos recursos naturais, além da maximização da qualidade dos frutos, nas

uvas por exemplo, a quantidade de radiação solar que a planta recebe, é um fator crucial para

determinar a quantidade de açúcar presente no fruto (DÍAZ et al., 2011).

### 4 PROCEDIMENTOS METODOLÓGICOS

O primeiro passo para dar início a execução do projeto é definir os requisitos do

sistema. Após isso será possível selecionar componentes e projetar o software baseado nos

requisitos definidos.

### 4.1 Definir requisitos do sistema

Quadro 3 – Requisitos do sistema

Requisitos não funcionais

Baixo custo
Eficiente energeticamente
Utilizar energia renovável Alta disponibilidade
Alta autonomia
Escalável
Automatizado
Sensores capaz de realizar leituras com no mínimo 95% de acurácia
Ser capaz de detectar faixas de temperatura, luminosidade e umidade dentro dos padrões para o ambiente de cultivo

Requisitos Funcionais

Permanecer em estado ativo somente enquanto necessário Transmitir os dados dos sensores e nível de tensão de alimentação periodicamente
Suportar personalização do período de leitura e transmissão de dados
Validar todos os dados obtidos antes de enviar para o roteador
Desativar todos os periféricos do microcontrolador que não serão utilizados
Quando ligado iniciar o modo de operação logo após configurar todos os periféricos
Ser capaz de operar utilizando somente energia solar, somente bateria ou ambos
Informar o estado do dispositivo através de um LED Possuir interruptores para ligar o sistema e para desativar a bateria de forma independente

Fonte: Elaborado pelo autor.

### 4.2 Definir protocolo de comunicação que será suportado pelo sistema

Em qualquer sistema baseado em WSN é necessário utilizar um protocolo de trans-

missão de dados para os dispositivos finais enviarem dados coletados ou receberem comandos

através de troca de mensagens. Dessa forma, a escolha do protocolo suportado pelo dispositivo

proposto neste trabalho deve se basear na complexidade da rede, no consumo e no alcance de

comunicação.

### 4.3 Análise dos componentes básicos de hardware do sistema

Os componentes básicos para o sistema funcionar são os elementos que compõem

os módulos de transmissão, sensoriamento e processamento.

### 4.3.1 Módulo de transmissão

Após definir o protocolo de comunicação, será possível escolher o melhor transmis-

sor, levando em conta a distância máxima de transmissão, frequências suportadas e seu consumo

no modo de transmissão e no modo de economia de energia.

### 4.3.2 Módulo de sensoriamento

Existem diversos tipos de sensores com o propósito de medir o mesmo fenômeno

físico ou químico. Esses sensores se diferenciam basicamente pelo grau de acurácia de leitura do

dado, consumo e interface de comunicação. Dessa forma se faz necessária a escolha de sensores

que sejam efetivos para a aplicação, considerando o custo/benefício e o consumo elétrico de

cada sensor individualmente.

### 4.3.3 Módulo de processamento

Após ter definido todos os componentes que serão controlados pelo sistema, é

possível definir qual o melhor microcontrolador para o sistema, levando em consideração os

recursos disponíveis, como quantidade de canais para comunicação, protocolos suportados,

memória flash, memória de programa e o consumo no modo de operação assim como no modo

de economia de energia.

### 4.4 Projetar sistema eletrônico e sistema de alimentação

Nesta etapa todos os componentes de Hardware já estarão definidos, dessa forma as

características elétricas de cada componente poderão ser analisadas através da documentação

disponibilizada pelo seu fabricante.

Em seguida o sistema eletrônico deverá ser projetado, incluindo o módulo de alimen-

tação que terá de ser composto por bateria recarregável e sistema de alimentação fotovoltaica,

para recarregar a bateria.

### 4.5 Implementar as funcionalidades de acordo com os requisitos

Este será o estágio da codificação de cada funcionalidade e drivers do sistema. Os

drivers serão responsáveis pela interface de comunicação com os sensores e com o módulo de

transmissão.

Entre as funcionalidades podemos listar:

- Leitura dos dados dos sensores;
- Transmissão dos dados;
- Configuração dos intervalos entre leituras e transmissões de dados;
- Configuração do modo de baixo consumo;
- Detecção de falhas nos sensores através da análise de consistência dos dados;
- Detecção de tensão de alimentação em nível baixo;
- Sistema de alerta em caso de falhas.

### 4.6 Montar um protótipo

Nesta etapa será criado um protótipo do sistema que incluirá todos os componentes

de hardware que por sua vez serão testados individualmente em condições ambientais variadas

artificialmente. Após isso será realizado o teste de integração com todos os componentes.

O protótipo será importante para analisar o comportamento dos sensores e realizar

ajustes nas rotinas de leitura e processamento de seus dados.

### 4.7 Definir os cenários de testes

Entre os testes devem estar incluídos a análise do comportamento de todos os

sensores em diferentes condições climáticas assim como a análise do comportamento do sistema

de alimentação.

### 4.8 Analisar, validar e apresentar os resultados

Os resultados obtidos serão analisados e comparados a fim de verificar sua consistên-

cia e relações entre si. A tensão de alimentação por exemplo deverá estar diretamente relacionada

com o nível de luminosidade.

### 5 RESULTADOS

Este capítulo apresenta os resultados obtidos na execução deste trabalho.

### 5.1 Protocolo de comunicação

O protocolo LoRa ® se mostra como mais adequado para o projeto, pois como foi

falado na seção 3, esse protocolo possui alto alcance de comunicação, baixo consumo e uma

arquitetura de rede simples, que facilita a escalabilidade do sistema.

### 5.2 Seleção de componentes de hardware

Com o objetivo de selecionar os componentes eletrônicos mais adequados para

atender os requisitos do projeto, foi separado alguns modelos viáveis de componentes. Para

cada tipo de componente foi elaborado uma tabela ou um gráfico, com as especificações de cada

modelo, para fins de comparação.

### 5.2.1 Módulo de transmissão

O módulo de transmissão é composto basicamente pelo transmissor LoRa ® e uma

antena que suporte a frequência 915 MHz que é a frequência utilizada no Brasil, como mostra a

Tabela 1.

Como pode ser observado no gráfico Figura 8, o transmissor SX1276 em relação ao

RN2903, além de possuir maior potência de transmissão, possui uma necessidade significativa-

mente menor de corrente, principalmente em potências de transmissão mais baixas. Além do

consumo no modo de transmissão, no modo ocioso o SX1276 necessita de uma corrente muito

baixa, apenas 1,5 µA (SEMTECH, 2015) enquanto que o RN2903 precisa de 2,8 mA (LoRa

Alliance Technical Commitee, 2017).

### 5.2.2 Módulo de sensoriamento

Os dispositivos de hardware que compõem este módulo são os sensores de tempera-

tura, umidade e luminosidade.

Figura 8 – Corrente de alimentação dos transmissores LoRa ® SX1276 e RN2903

20

40

60

80

100

120

8 | 10 | 12 | 14 | 16

Corrente de alimentação (mA)

Potência de TX (dBm)

SX1276
RN2903

Fonte: Elaborado pelo autor.

5.2.2.1 Sensor de temperatura e umidade do ar

Como pode ser observado na Tabela 2 os modelos se diferenciam basicamente pela

precisão de leitura, consumo e tempo de resposta. O sensor SHT30 se mostra como melhor

opção, pois além de ter o menor consumo, possui o menor tempo de resposta e sua precisão de

leitura dos dados estão dentro dos requisitos para o projeto.

Tabela 2 – Modelos de sensor de Temperatura/Umidade

Sensor | Acurácia (umidade / temperatura) | Corrente de alimentação (leitura / ocioso) | Tempo de resposta
SHT10 | 4,5% / ±0,5 °C | 550 - 1000 µA / 0,3 - 1,5 µA | 8 - 30 s
SHT21 | 2% / ±0,3 °C | 300 - 330 µA / 0,15 - 0,4 µA | 8 - 30 s
SHT25 | 1,8% / ±0,2 °C | 300 - 330 µA / 0,15 - 0,4 µA | 8 - 30 s
SHT30 | 3% / ±0,3 °C | 220 - 300 µA / 0,2 - 2 µA | 2 - 8 s

Fonte: Elaborado pelo autor.

5.2.2.2 Sensor de temperatura do solo

O sensor de temperatura DS18B20 foi selecionado para medir temperaturas do solo.

Uma grande vantagem de utilizar esse sensor é o seu encapsulamento do tipo TO-92, que facilita

sua fixação em um tubo de aço pequeno, de forma que se torne resistente à água e umidade. Isso é necessário pois esse sensor em particular deverá ser introduzido no solo, logo será exposto

diretamente à água.

5.2.2.3 Sensor de umidade do solo

O sensor responsável por realizar leituras relacionada ao nível de umidade presente

no solo é um sensor capacitivo. Assim como o sensor de temperatura do solo, este deverá ser

introduzido no solo, por esse motivo deve ser resistente à água.

5.2.2.4 Sensor de luminosidade

Como podemos notar na Tabela 3 o sensor MAX44099 se mostra como a melhor

opção para o projeto pois além de possuir o menor consumo das três opções selecionadas para

análise, ele é capaz de medir níveis de luminosidades de até 188,006 Lux.

Tabela 3 – Modelos de sensor de Luminosidade

Sensor | Faixa de medição | Corrente de alimentação (leitura) | Corrente de alimentação (ocioso)
TSL2561 | 0,1 - 40000 Lux | 0,24 - 0,6 mA | 3,2 - 15 µA
BH1750FVI | 1 - 65536 Lux | 120 - 190 µA | 0,01 - 1 µA
MAX44099 | 0,045 - 188006 Lux | 1,6 µA | 0,65 - 1,2 µA

Fonte: Elaborado pelo autor.

### 5.2.3 Módulo de processamento

A família de microcontroladores PIC16F18446 (INC, 2017) da fabricante Microchip

Technology é voltada para aplicações similares a do trabalho proposto. Os dispositivos perten-

centes a essa família se destacam por possuir alguns modos de operação de baixo consumo,

conversores analógicos de alta precisão e suportar protocolos de comunicação como SPI, I2C e

UART.

Os diferenciais que fazem com que o microcontrolador PIC16F18426 se mostre

como melhor opção para o projeto são os seguintes (INC, 2017):

- 2 canais para comunicação SPI e I2C;
- Conversor analógico-digital de 12 bits;
- Temporizadores de até 24 bits;
- Tensão de referência fixa;
- Oscilador interno de até 32 MHz;

- Pinos multiplexados com funções personalizáveis;
- Encapsulamento do tipo PDIP disponível.
- Opera na faixa de 2,3 até 5,5 V;
- Corrente de alimentação de 32 uA para cada 1 MHz do oscilador, para tensão de ali-

mentação 1,8 V. Exemplo: Oscilador configurado em 8 MHz resulta em uma corrente de

alimentação de 256 uA.

### 5.2.4 Módulo de alimentação

O sistema de alimentação é composto pelos seguintes componentes: bateria, circuito

carregador, painel solar e regulador de tensão.

- Bateria – O modelo NCR18650B foi escolhido por ser recarregável, possuir uma larga

capacidade de 3350 mAh, e ser capaz de suprir o sistema com a corrente necessária para

alimentar todos os componentes (PANASONIC, 2012).

- Circuito carregador – O carregador TP4056 é um componente capaz de carregar baterias

de lítio a partir de uma fonte de tensão de até 8 Volts.

- Placa solar – O modelo de placa solar adotado fornece uma tensão de até 5,8 Volts,

dependendo da intensidade solar a qual está sendo exposta. Esta placa solar juntamente

com o circuito carregador TP4056 será capaz de alimentar o sistema e recarregar a bateria

quando houver luz do sol sobre a placa.

- Regulador de tensão – O intuito de utilizar o regulador de tensão LM2596 (Texas Ins-

truments, 2016) é garantir que a tensão de alimentação fornecida pelo circuito não irá

ultrapassar a tensão de operação dos componentes, o que poderia danifica-los.

### 5.3 Esquemático e desenho da placa

Para desenho e implementação do circuito e da placa, foi utilizado o software EAGLE

juntamente com bibliotecas disponibilizadas na internet. O esquemático completo e o

desenho da placa se encontram nos apêndices A e B respectivamente.

### 5.3.1 Configuração dos pinos do microcontrolador

Uma das vantagens de utilizar o PIC16F18426 é que ele suporta a personalização dos

seus pinos, ou seja, há a possibilidade de escolher quais pinos do microcontrolador cada periférico irá utilizar, o que facilitou bastante na hora do roteamento e desenho da placa.

### 5.3.2 Módulo de alimentação

Este módulo possui um conector que funciona como entrada para os cabos do painel solar,

além disso, dispõe de um regulador de tensão que é responsável por converter a tensão

provinda da bateria ou do painel solar em uma tensão menor. Isso se faz necessário devido

3,3 Volts ser a tensão que os sensores e o transmissor operam, enquanto que os níveis de

tensão fornecidos pela bateria ou painel solar podem chegar em até 5,8 Volts, dependendo

da intensidade do sol que o painel solar é exposto.

Existem dois interruptores para ativar ou desativar a bateria e o sistema de alimentação

como um todo, como pode ser observado na Figura 9, que se trata do esquemático do

circuito responsável pela alimentação do sistema.

Figura 9 – Esquemático do circuito de alimentação.

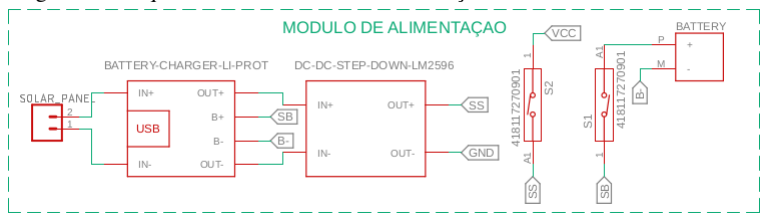
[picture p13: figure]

Fonte: Elaborado pelo autor.

### 5.3.3 Módulo de sensoriamento

O Circuito do módulo responsável por coletar os dados é composto basicamente pelos seus

quatro sensores. O sensor DS18B20 em particular necessita de um resistor para formar um

divisor de tensão entre um dos seus pinos e o pino de alimentação (INTEGRATED, 2017).

É importante destacar que os sensores SHT30 e MAX44009 compartilham os mesmos

pinos, já que utilizam o mesmo protocolo de comunicação (I2C), que permite esse tipo de

configuração mostrada na Figura 10.

Figura 10 – Esquemático do circuito de sensoriamento.

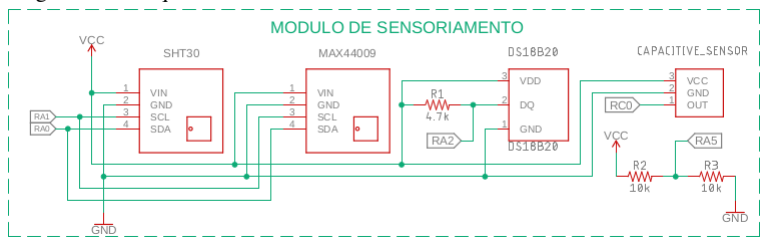
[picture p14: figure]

Fonte: Elaborado pelo autor.

### 5.3.4 Microcontrolador, transmissor e led

O esquemático da Figura 11 demonstra as conexões do microcontrolador, do led e do

transmissor.

Figura 11 – Esquemático do circuito do microcontrolador, transmissor e led.

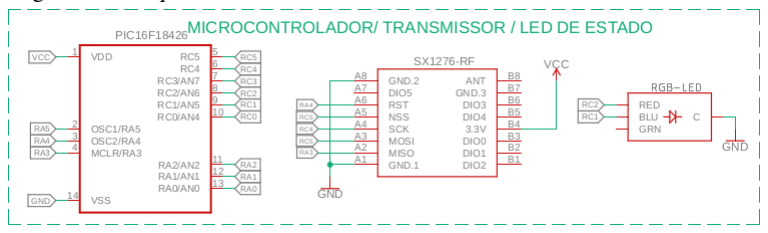
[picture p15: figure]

Fonte: Elaborado pelo autor.

### 5.3.5 Desenho da placa

A placa para o protótipo foi confeccionada conforme o desenho da Figura 12.

### 5.4 Software do sistema

Entre os componentes de Software do sistema estão inclusos os drivers de cada periférico

do microcontrolador, drivers de cada componente da placa, como sensores e transmissor e o

software da execução principal, que integra todos os componentes e periféricos do sistema.

Nesta seção é demonstrado alguns trechos de código escritos durante a implementação do

software do sistema, o código fonte completo e outros detalhes do sistema estão disponíveis

no repositório do projeto 1

1 <https://www.github.com/emanuel36/LoRaWAN-sensor-node-device>

Figura 12 – Desenho da placa do protó-

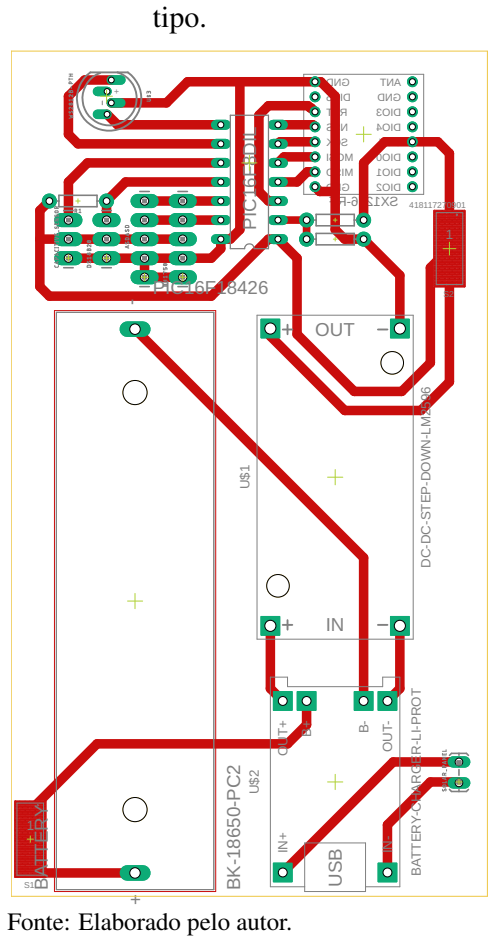
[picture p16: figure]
tipo.; OUT; B+B- USB; OUT+ OUT-; BATTERY; DC-DC-STEP-DOWN-LM2596 BATTERY-CHARGER-LI-PROT; 418117270901 PIC¹⁶F8DIL; Fonte: Elaborado pelo autor.

### 5.4.1 Ferramentas utilizadas

5.4.1.1 MPLAB X IDE

A IDE de programação MPLAB é disponibilizada pela fabricante do microcontrolador e

foi utilizada para escrever todo o software pois além de possuir diversas ferramentas que

auxiliam no processo de codificação, possui integração com o circuito de debug PICkit3

(Microchip Technology Inc., 2012).

5.4.1.2 Circuito de debug PICkit 3

O PICkit 3 é uma ferramenta produzida pela mesma fabricante do microcontrolador do

projeto (PIC16F18426). Entre suas principais funcionalidades inclui-se o processo de

gravação do software na memória de programa do microcontrolador, o que faz desse

circuito um componente essencial durante todos os processos que envolvem escrita ou alteração no software (MICROCHIP, 2013).

### 5.4.2 Configurações dos periféricos do microcontrolador

Cada periférico listado abaixo teve seu driver implementado e configurado pelo autor, se

baseando na documentação disponibilizada pelo fabricante.

1. Oscilador interno – Configurado na sua frequência máxima de 32 MHz, gerando o

clock principal do sistema. Todos os periféricos foram configurados para obter seu

respectivo clock a partir do sinal gerado por este oscilador.

2. Conversor analógico-digital – Este módulo realiza as leituras do sensor capacitivo

e da tensão de alimentação. Foi configurado para utilizar uma precisão de 12 bits,

frequência de 800 kHz e utilizar a tensão de referência provinda do módulo de tensão

de referência fixa.

3. Referência fixa de tensão – Configurado para fornecer uma tensão de referência de

2,048 Volts para o módulo ADC.

4. OneWire – Protocolo de comunicação implementado manualmente utilizando Gene-

ral Purpose Input/Output (GPIO), pois o microcontrolador não dispõe de um circuito

ou módulo exclusivo para este protocolo.

5. SPI – Este módulo é responsável pela comunicação entre o microcontrolador e o

transmissor LoRa ®Configurado na frequência 4 MHz utilizando um GPIO como ˙

slave select.

6. I2C – Este periférico é utilizado na comunicação do microcontrolador com os sensores

SHT30 e MAX4409. Foi configurado para executar na frequência 400 kHz com 9600

de Baud Rate.

7. Interrupções – Responsável por despertar o núcleo de processamento quando alguma

execução for necessária.

8. Temporizadores – Um dos temporizadores foi configurado para gerar uma interrupção

periodicamente, a fim de despertar o sistema e realizar leituras e transmissão dos

dados. O período de cada ciclo pode ser configurado entre 5 e 80 minutos, para

tempo mínimo e máximo respectivamente. Outro temporizador é responsável por

acordar o sistema para fazê-lo ligar e desligar o LED de estado.

9. Gerenciador de pinos – Foi configurado de modo a facilitar o desenho e roteamento

das trilhas na placa.

10. Desativador de periféricos – Foi utilizado para desativar todos os módulos e periféri-

cos não utilizados, em busca de economizar energia.

### 5.4.3 Função principal

A função main é encarregada de inicializar todo o sistema e colocar-lo em modo de

economia de energia logo após executar qualquer rotina de interrupção, como podemos

observar no Código-fonte 1. Dessa forma na grande parte do tempo o sistema está em

modo de economia de energia, logo, o consumo é minimizado bastante, pois quando os

componentes são postos em modo de economia de energia o consumo cai drasticamente, o

microcontrolador por exemplo precisa de uma corrente de apenas 50 nA neste modo.

Código-fonte 1 – Função principal

1 | void main () {
2 | SYSTEM_Initialize () ;
3 | while (1) {
4 | SLEEP () ;
5 | }
6 | }

### 5.4.4 Inicialização do sistema

A rotina de software do Código-fonte 2 responsável por inicializar o sistema tem como

objetivo configurar todos os componentes presentes na placa, de forma que seja possível a

utilização desses sempre que solicitado a cada período.

Código-fonte 2 – Função de inicialização do sistema

1 | void SYSTEM_Initialize () {
2 | OSCILLATOR_Initialize () ;

3 | SLEEP_Inicialize () ;
4 | PIN_MANAGER_Initialize () ;
5 | TMR0_Initialize ( T5_MINUTES ) ;
6 | TMR2_Initialize () ;
7 | INTERRUPT_GlobalInterruptEnable () ;
8 | INTERRUPT_PeripheralInterruptEnable () ;
9 | setSystemStatus ( WARNING );
10 | statusLed_Inicialize () ;
11 | ADC_Initialize () ;
12 | I2C_Initialize () ;
13 | SPI2_Initialize () ;
14 | oneWirePinInicialize () ;
15 | supplyPinInicialize () ;
16 | soilMoistureSensorPinInicialize () ;
17 | max44009Setup () ;
18 | SHT30Setup () ;
19 | ds18b20Setup () ;
20 | SX1216_Inicialize (915000000) ;
21 | }

A função TMR0_Initialize(uint8_t period) em particular recebe um parâmetro de acordo

com o Código-fonte 3 que é o tempo no qual o sistema fica em economia de energia antes

executar a rotina de leitura e transmissão de dados. Essa função configura um dos módulos

de temporização, de modo que o sistema seja despertado periodicamente.

Após realizar todos os procedimentos de inicialização com sucesso, o sistema sinaliza que

está tudo normal e entra em modo de economia de energia até ser despertado pelo módulo

temporizador.

Código-fonte 3 – Estrutura que contém os perídos configuráveis do temporizador

1 enum periods { T5_MINUTES ,

2 | T10_MINUTES ,
3 | T15_MINUTES ,
4 | T20_MINUTES ,
5 | T25_MINUTES ,
6 | T30_MINUTES ,
7 | T35_MINUTES ,
8 | T40_MINUTES ,
9 | T45_MINUTES ,
10 | T50_MINUTES ,
11 | T55_MINUTES ,
12 | T60_MINUTES ,
13 | T65_MINUTES ,
14 | T70_MINUTES ,
15 | T75_MINUTES ,
16 | T80_MINUTES } period ;
17 | }

### 5.4.5 Rotina de interrupção

A rotina de interrupção que é executada periodicamente é o Código-fonte 4, basicamente

realiza leitura dos sensores, analisa os dados coletados, monta o pacote com os dados e o

transmite.

Código-fonte 4 – Função executada periodicamente

1 | void callBack () {
2 | sensorsRead () ;
3 | systemCheck () ;
4 | pktBuild () ;
5 | SX1276Transmit () ;
6 | }

### 5.4.6 Modo de alerta

O dispositivo possui um sistema de estado que utiliza um LED para transmitir informações

visualmente. Quanto o sistema está operando normalmente sem nenhum tipo de erro ou

dado inconsistente, o LED pisca na cor azul e quando o sistema é colocado em modo de

alerta, o LED de estado passa a piscar na cor vermelha. Se for considerado um campo

com diversos dispositivos, o LED piscando ajuda bastante na localização de dispositivos

defeituosos. Além de informar o estado pelo LED, o sistema envia o seu estado em cada

mensagem transmitida.

### 5.5 Protótipo

O protótipo do sistema foi confeccionado em uma placa de fenolite cobreada, de acordo

com o desenho do circuito da Figura 12. Como pode ser visualizado na Figura 13 ,a

maioria dos componentes foram soldados diretamente na placa, com exceção dos sensores

e da placa solar, que se conectam a placa através de conectores e cabos, o que permite uma

maior mobilidade destes.

Figura 13 – Versão final da placa do protótipo.


Fonte: Elaborado pelo autor.

A placa possui dois interruptores, um deles tem como função ligar e desligar o sistema, já o

segundo é conectado ao terminal positivo da bateria, de modo que seja possível desconectar

a bateria do circuito fazendo com que o sistema seja alimentado apenas pela placa solar.

### 5.6 Testes

Para realizar os testes foi colocado areia em uma caixa de papelão perfurada, de forma

que a água pudesse escapar lentamente, deixando a areia menos úmida com o passar do

tempo. Os sensores de temperatura e umidade do solo foram introduzidos dentro da caixa

de modo que pudessem coletar os dados relacionados à areia contida ali.

A placa foi posicionada dentro de uma caixa de isopor com alguns furos que serviram de

passagem para os cabos dos sensores e da placa solar, que foram posicionados do lado

externo da caixa de isopor, como pode ser observado na Figura 14.

Figura 14 – Dispositivo em estado de operação.


Fonte: Elaborado pelo autor.

O Software foi configurado para gerar uma interrupção periodicamente, de modo que seja

coletadas as informações dos sensores e transmitidas a cada 5 minutos. Os testes e ajustes

nos sensores começaram no dia 13/11/2019. Com os sensores ajustados, foi iniciado uma

coleta de dados em um período interrupto de 24 horas, que foi iniciado às 18:00 do dia

19/11/2019 e se estendeu até às 18:00 do dia 20/11/2019.

O dispositivo foi posicionado em um local que ficou exposto a luz solar tanto no período

da manhã, quanto no período da tarde.

### 5.6.1 Transmissor LoRa ® SX1276

Um roteador foi implementado utilizando uma placa de desenvolvimento Raspberry Pi

3 a partir de um tutorial 2 disponível no site <https://www.embarcados.com.br>. Esse

roteador pode ser acessado através do protocolo de rede SSH.

O roteador e o transmissor foram configurados de acordo com os seguintes parâmetros:

– Roteador

* Frequência - 915 MHz

* Fator de espalhamento - 7

* Largura de banda - 125 kHz

– Transmissor

* Frequência - 915 MHz

* Fator de espalhamento - 7

* Largura de banda - 125 kHz

* Potência de transmissão 17 dBm

Para testar os drivers e a eficácia do transmissor foi enviado um pacote para o roteador

conforme o Código-fonte 5.

Código-fonte 5 – Função executada periodicamente

1 | void SX1276Transmit () {
2 | beginPacket () ;
3 | SX1276WriteString ("UFC - CAMPUS QUIXADA ") ;
2 | <https://www.embarcados.com.br/lora-arduino-raspberry-pi-shield-dragino/>

4 | endPacket () ;
5 | }

Como pode ser visualizado abaixo, o roteador recebeu o pacote e codificou a mensagem

utilizando o protocolo base64, dessa forma para visualizar a mensagem é necessário utilizar

um decodificador 3
1 | pi@raspberrypi :~/ single_chan_pkt_fwd $ ./
| single_chan_pkt_fwd
2 | SX1276 detected , starting .
3 | Gateway ID : b8 :27: eb : ff : ff :8 d : e5 : b3
4 | Listening at SF7 on 915.000000 Mhz .
5 | ------------------
6 | stat update : {" stat ":{" time ":" 2019 -11 -22 01:11:10 GMT
| "," lati " : -4.97007 , " long " : -39.01793 , " alti ":0 ," rxnb "
| :0 ," rxok ":0 ," rxfw ":0 ," ackr ":0.0 ," dwnb ":0 ," txnb ":0 ,
| " pfrm ":" Single Channel Gateway "," mail ":"
| robertcabral@alu . ufc .br"," desc ":" Teste "}} Packet
| RSSI : -52 , RSSI : -44 , SNR : 9 , Length : 20
7 | rxpk update : {" rxpk " :[{ " tmst " :387081419 , " chan ":0 ,"
| rfch ":0 ," freq " :915.000000 , " stat ":1 ," modu ":" LORA ","
| datr ":" SF7BW125 "," codr ":"4/5 "," lsnr ":9 ," rssi ": -52 ,
| " size ":20 ," data ":" VUZDIC0gQ0FNUFVTIFFVSVhBREE =" }]}

Para o envio de mensagem contendo os dados dos sensores, foi adotado o formato ascii.

Os dados são separados por uma barra e a ordem dos dados são: status do sistema, tensão

de alimentação, temperatura do ar, temperatura do solo, umidade do ar, umidade do solo e

luminosidade. O valor de status pode assumir 0 ou 1 para estado normal e estado de alerta,

respectivamente.

Um exemplo de mensagem com dados dos sensores recebida pelo roteador pode ser

visualizado abaixo:

3 <https://www.base64decode.org/>

1 0|3.327|31.37|30.31|53.59|26.6|21.4

### 5.6.2 Luminosidade

O gráfico da Figura 15 ilustra os níveis de luminosidade coletados através do sensor

MAX44009 que estão de acordo com o esperado, visto que no período da manhã o céu

estava um pouco nublado e durante à tarde o céu estava bastante ensolarado. Durante o

período de 18:00 até 4:00 horas os níveis de luminosidade coletados não passaram de 0

Lúmens e a partir de 4:50, horário que o sol nasceu, os níveis de luminosidade começaram

a aumentar, e depois de meio dia começaram a diminuir até anoitecer e atingir 0 Lúmens.

Figura 15 – Níveis de Luminosidade

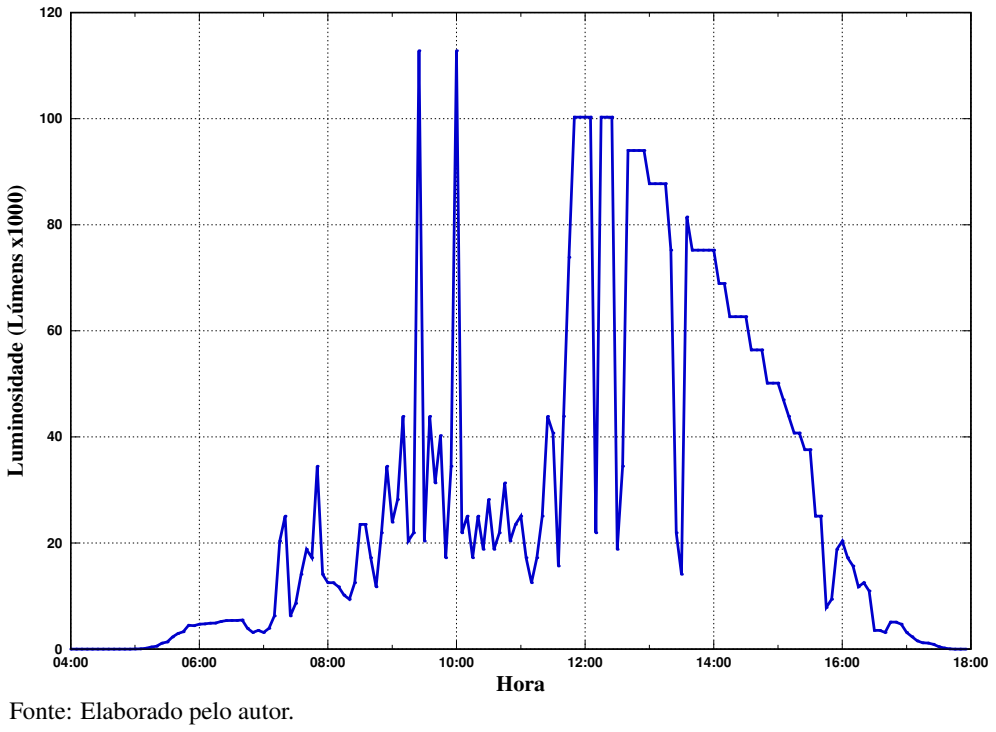
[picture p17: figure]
Luminosidade (Lúmens x1000); Hora; Fonte: Elaborado pelo autor.

### 5.6.3 Temperatura

No gráfico da Figura 16 é demonstrado os níveis de temperatura do solo e do ar, coletados

através dos sensores DS18B20 e SHT30 respectivamente. Conforme esperado durante

o período da tarde as temperaturas foram maiores enquanto que durante a madrugada as temperaturas caíram bastante.

Figura 16 – Níveis de Temperatura

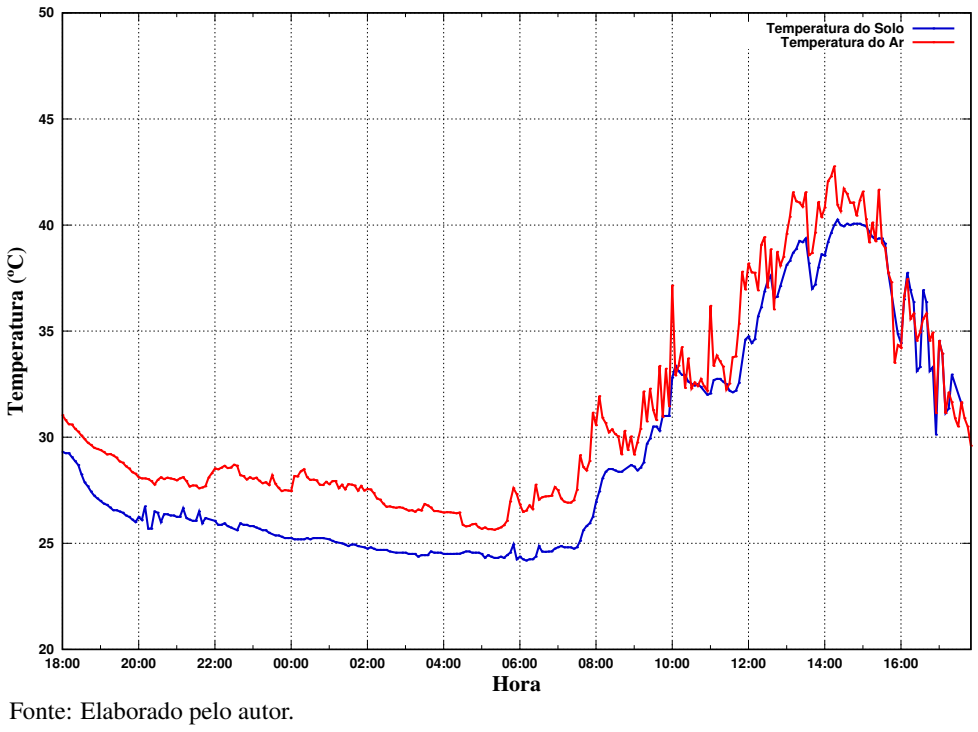
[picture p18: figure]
Temperatura (ºC); Hora; Temperatura do Solo Temperatura do Ar; Fonte: Elaborado pelo autor.

### 5.6.4 Umidade

5.6.4.1 Umidade do ar

Os dados relacionados a umidade do ar podem ser visualizados no gráfico da Figura

17. Durante o período noturno os níveis de umidades atingiram valores mais elevados,

conforme esperado.

5.6.4.2 Umidade do solo

O sensor capacitivo utilizado possui um terminal que emite uma tensão que varia de acordo

com o nível de umidade do solo. Através de testes foi analisado a variação dessa tensão

em diversas situações com a areia muito molhada e com a areia muito seca e a partir dessa

análise foi desenvolvido um algoritmo com a Equação 5.1 para retornar o valor da umidade

Figura 17 – Níveis de Umidade relativa do Ar

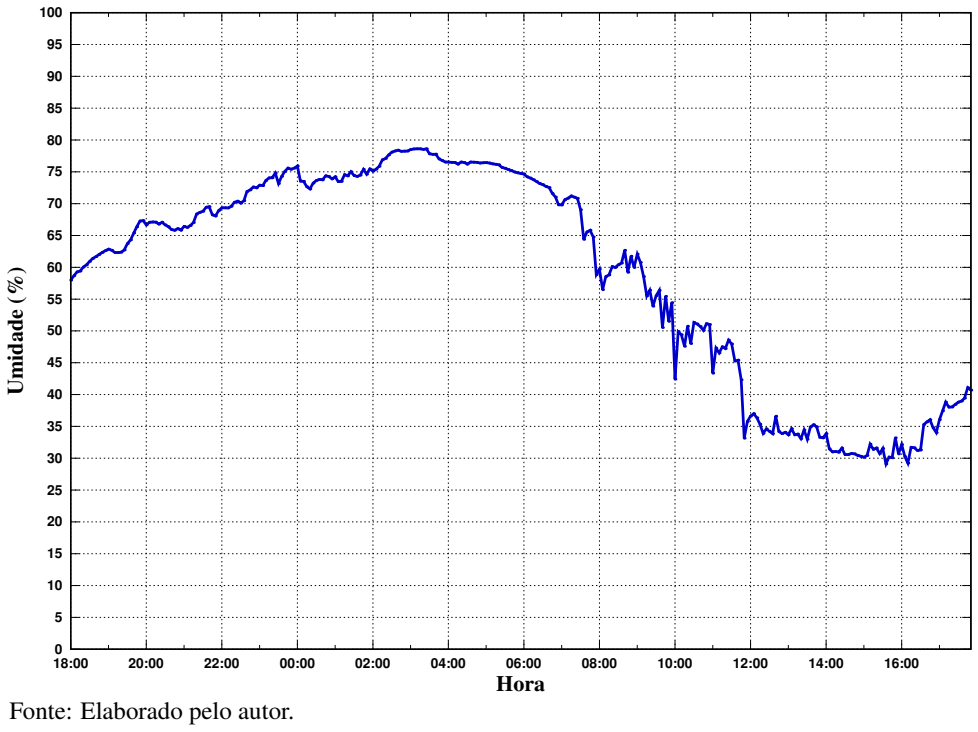
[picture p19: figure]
Umidade (%); Hora; Fonte: Elaborado pelo autor.

em uma escala de 0 até 30, sendo 0 o menor e 30 o maior nível de umidade possível.

Umidade = 100 ∗ [0.7 − (Tensão do sensor/Tensão de alimentação)] | (5.1)

O gráfico da Figura 18 ilustra os níveis de umidade da areia coletados através do sensor

capacitivo. Nos momentos próximos as 22:00 e 12:00 foi despejada água na areia, isso

explica a mudança abrupta de umidade, após as aplicações a umidade começou a diminuir.

Durante o período diurno a umidade do solo decresceu bem mais rápido devido alguns

fatores, especialmente a temperatura do solo que chegou a ultrapassar os 40°C durante à

tarde.

### 5.6.5 Tensão de Alimentação

Para realizar a leitura do nível de tensão da alimentação do sistema foi utilizado o perifé-

rico conversor analógico-digital em conjunto com a referência fixa de tensão interna do

microcontrolador. As opções de tensão de referência do PIC16F18426 são: 1.024, 2.048 e

4.096 Volts. Devido este valor não poder ser maior que a tensão de alimentação, o valor

selecionado foi 2.048 V, já que a alimentação é de 3.3 V. Isso significa que ao utilizar

Figura 18 – Níveis de Umidade do solo

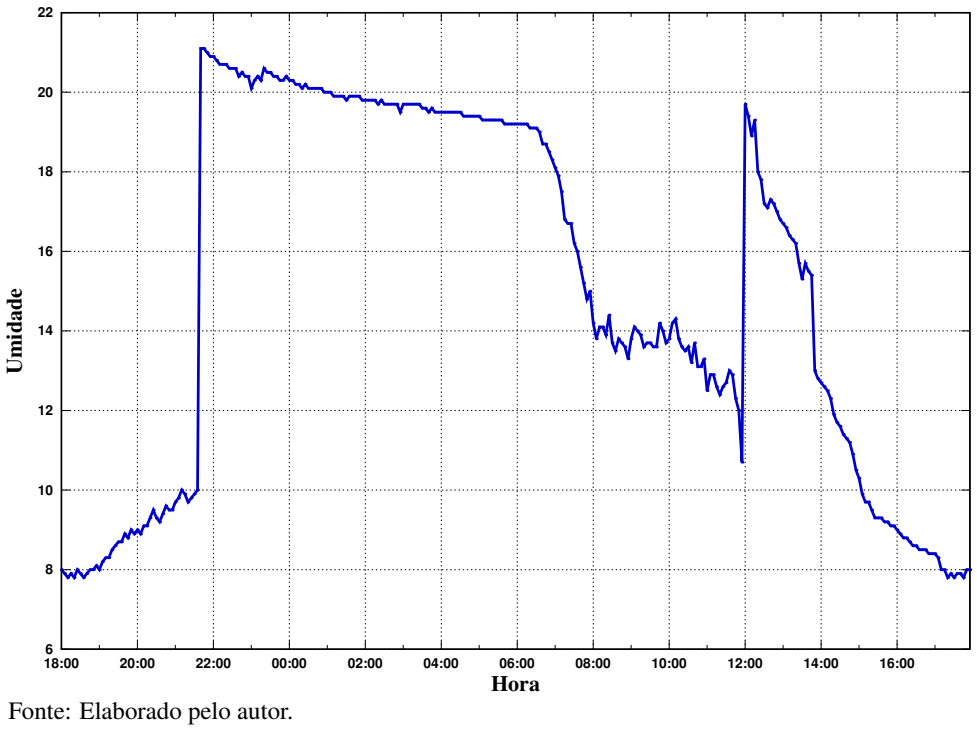
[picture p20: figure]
Umidade; Hora; Fonte: Elaborado pelo autor.

somente o conversor analógico digital não é possível medir tensões maiores 2.048 V visto

que esse é o valor de referência.

Contudo é necessário medir tensões maiores que 2.048 V, para que isso seja possível foi

adotado o uso de um circuito divisor de tensão com dois resistores de valor 10 kΩ de

acordo com a Figura 19, logo, o resultado obtido na medição deve ser dobrado. Este valor

de resistência adotado resulta em um valor de resistência total de 20 kΩ, logo a corrente

que irá percorrer esses resistores será aproximadamente 1,65 µA que é suficientemente

pequena para não demandar muito da bateria e suficientemente alta para o conversor

analógico-digital detectar o nível de tensão.

Figura 19 – Divisor de tensão com dois resistores de 10 kΩ

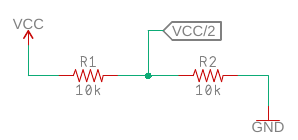
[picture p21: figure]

Fonte: Elaborado pelo autor.

Como pode ser visualizado no gráfico da Figura 20, durante o período noturno a tensão

de alimentação caiu aos poucos, isso aconteceu devido o sistema está sendo alimentado

apenas pela bateria, já que não há luz solar, logo os painéis solares não geram energia

durante este período. A partir do momento em que há luz solar suficiente para gerar

energia o sistema passa a ser alimentado também através do painel solar, e a bateria é

carregada. Durante o período da tarde houve uma maior incidência de luz solar como

pode ser observado no gráfico da Figura 15, dessa forma a bateria pode ser carregada mais

rapidamente durante este período.

Figura 20 – Níveis de Tensão de Alimentação

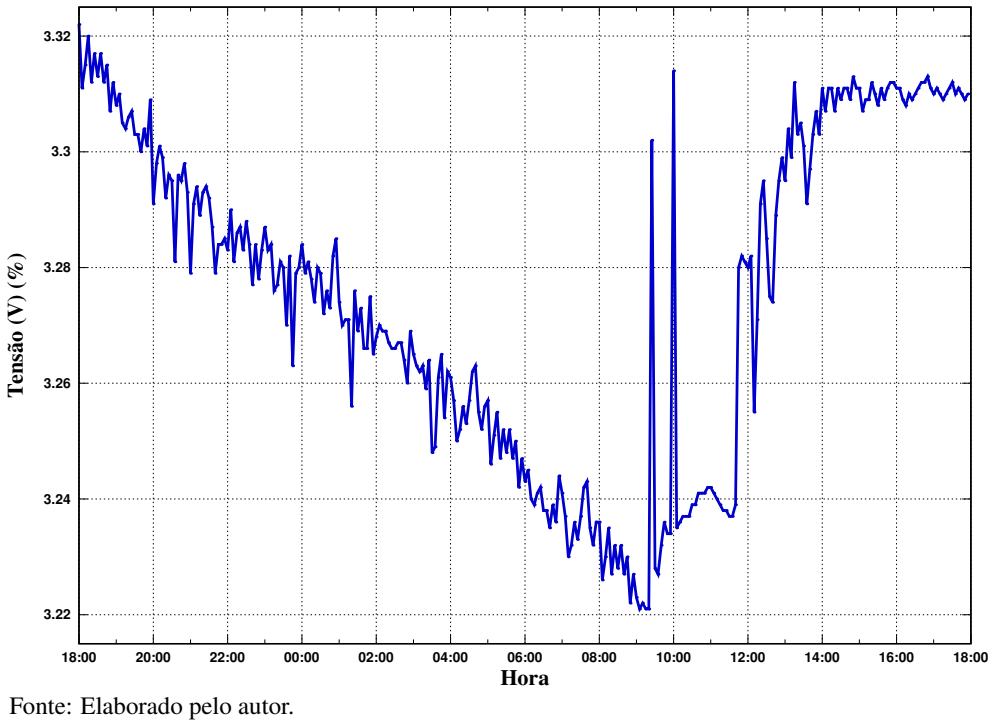
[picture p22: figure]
Tensão (V) (%); Hora; Fonte: Elaborado pelo autor.

Observando o gráfico das Figuras 21 e 22 podemos notar que entre 9:00 e 10:00 a

luminosidade passa de um valor baixo paro um valor bem alto, e isso resulta em uma

elevação na tensão de alimentação devido a placa solar começar a fornecer energia ao

sistema. Já entre 12:00 e 14:00 algumas nuvens interceptaram a luz solar e isso fez com

que o painel solar parasse de funcionar, logo a bateria que não estava completamente

carregada passou a alimentar o sistema, o que explica a queda de tensão.

É importante ressaltar que o valor de tensão da bateria aumentou significantemente no

período da tarde, logo podemos chegar a conclusão que a bateria recarregou através da

energia fornecida pelo painel solar.

Figura 21 – Níveis de luminosidade entre 08:00 e 15:00

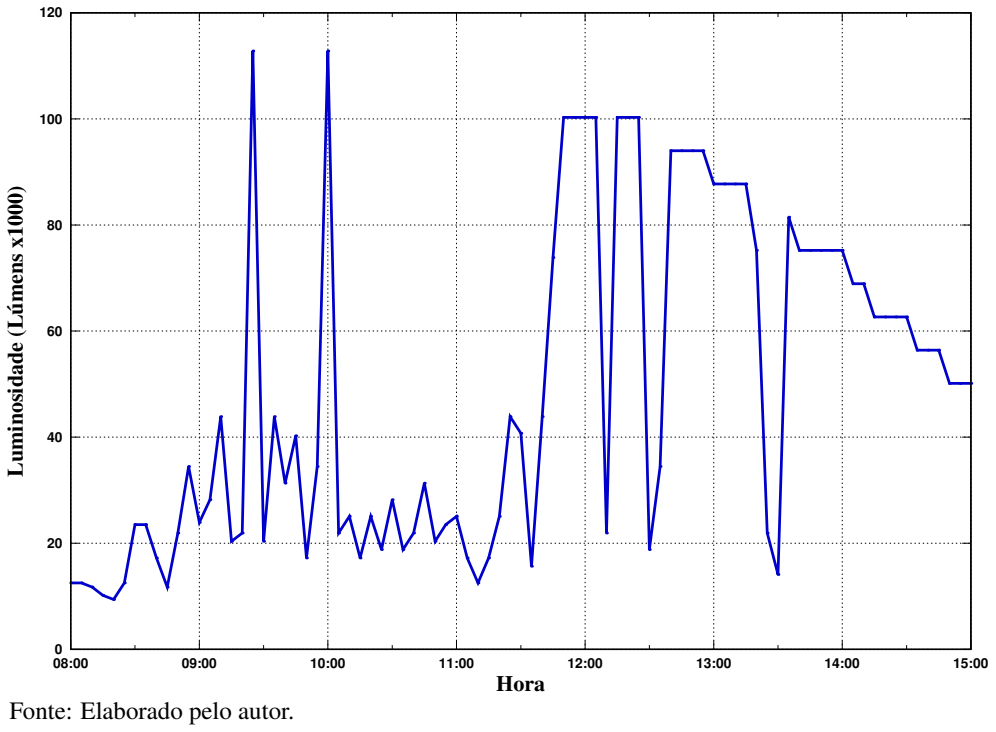
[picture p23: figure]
Luminosidade (Lúmens x1000); Hora; Fonte: Elaborado pelo autor.

Figura 22 – Níveis de tensão de alimentação entre 08:00 e 15:00

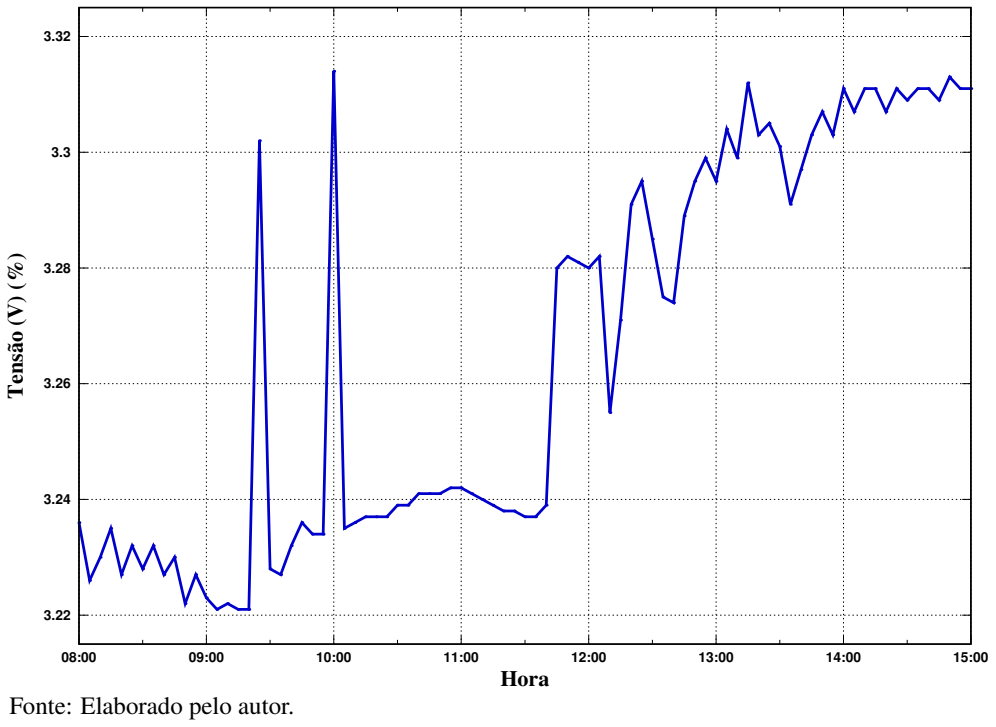
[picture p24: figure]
Tensão (V) (%); Hora; Fonte: Elaborado pelo autor.

### 6 CONSIDERAÇÕES FINAIS

Esse trabalho apresentou o processo de implementação de um dispositivo utilizando

tecnologias que estão em ascensão na área de sistemas embarcados, como LoRaWAN ® e energia

solar. Um dos fatores que mais influenciou no processo seletivo de componentes foi consumo de

energia, desde que o componente desempenhe seu papel de modo que cumpra os requisitos do

sistema.

Entre as principais tarefas, codificar os drivers dos periféricos foi o que demandou

mais tempo, visto que o microcontrolador utilizado no projeto é novo e não possui bibliotecas

prontas, logo foi necessário implementar praticamente tudo. O desenvolvimento do firmware

do transmissor SX1276 foi o que demandou mais tempo, cerca de 70% do tempo total gasto na

implementação do dispositivo. Isso aconteceu devido o SX1276 não ser um transmissor fácil

de utilizar, selecionar o transmissor RN2903 para o projeto facilitaria bastante o processo de

implementação, contudo o custo do sistema iria ultrapassar o dobro do sistema utilizando o

SX1276, logo utilizar o transmissor mais barato foi uma decisão que valeu a pena.

O processo de construção do dispositivo foi bem rápido e tudo saiu como esperado,

além disso alguns problemas relacionados a conexões e interferências foram solucionados ao

migrar os componentes da protoboard para a placa PCB. Os sensores se mostraram bastante

acurados, pois os dados coletados estão de acordo com as condições climáticas do local no

qual o dispositivo foi testado. Alguns testes relacionados a consumo e distância máxima de

comunicação poderiam ser sido feitos, contudo foi dado foco em fazer o transmissor funcionar

para satisfazer todos os objetivos específicos.

Como trabalhos futuros pretende-se implementar um modo de debug para o disposi-

tivo, de forma que seja possível ajustar algumas configurações tais como tempo de cada ciclo,

precisão dos sensores e modos de operação, sem a necessidade de recompilar o código fonte e

gravar novamente. Em adição, a plataforma de debug será uma aplicação móvel que utilizará o

protocolo de transmissão bluetooth, de forma que seja possível acessar e alterar facilmente as

configurações através de um smartphone ou tablet, sem a necessidade de utilizar cabos.

REFERÊNCIAS

AI-THINKER. ESP-01 WiFi Module. 2015. Disponível em: <http://ecksteinimg.de/Datasheet/Ai-thinkerESP-01EN.pdf>.

ALVES, R. ANA e Embrapa concluem levantamento sobre irrigação com pivôs centrais no Brasil. 2015. Disponível em: <http://www2.ana.gov.br/Paginas/imprensa/noticia.aspx?id_noticia=12669>. (http://www2.ana.gov.br/Paginas/imprensa/noticia.aspx?id_noticia=12669) Acesso em: 21 mar. 2019.

ANASTASI, G.; BORGIA, E.; CONTI, M.; GREGORI, E. IEEE 802.11 ad hoc networks: Performance measurements. Proceedings - 23rd International Conference on Distributed Computing Systems Workshops, ICDCSW 2003, p. 758–763, 2003.

BALBINOT, A.; BRUSAMARELLO, V. Instrumentação e fundamentos de medidas. Grupo Gen - LTC, 2011. ISBN 9788521618799. Disponível em: <https://books.google.com.br/books?id=HBZCAwEACAAJ>. (https://books.google.com.br/books?id=HBZCAwEACAAJ)

BOARD, N. S.; COUNCIL, N. R. et al. Technology for the United States Navy and Marine Corps, 2000-2035: Becoming a 21st-century Force: V. 3, Information in Warfare. [S.l.]: National Academies, 1997.

DAVIS, G.; CASADY, W. W.; MASSEY, R. E. Precision agriculture: An introduction. Extension publications (MU), University of Missouri Extension, 1998.

DEVALAL, S.; KARTHIKEYAN, A. LoRa Technology - An Overview. Proceedings of the 2nd International Conference on Electronics, Communication and Aerospace Technology, ICECA 2018, IEEE, n. Iceca, p. 284–290, 2018.

DÍAZ, S. E.; PÉREZ, J. C.; MATEOS, A. C.; MARINESCU, M. C.; GUERRA, B. B. A novel methodology for the monitoring of the agricultural production process based on wireless sensor networks. Computers and Electronics in Agriculture, Elsevier B.V., v. 76, p. 252–265, 2011. ISSN 01681699. Disponível em: <http://dx.doi.org/10.1016/j.compag.2011.02.004>.

FARAHANI, S. ZigBee Basics. ZigBee Wireless Networks and Transceivers, p. 1–24, 2009.

FORSTER, A. Introduction to wireless sensor networks. [S.l.]: John Wiley & Sons, 2016. ISBN 9781118993514.

GARCÍA-HERNÁNDEZ, C.; IBARGÜENGOYTIA-GONZÁLEZ, P.; GARCÍA-HERNÁNDEZ, J.; PÉREZ-DÍAZ, J. Wireless Sensor Networks and Applications: a Survey. IJCSNS International Journal of Computer Science and Network Security,
v. 7, p. 264–273, 2007. Disponível em: <http://campus.cva.itesm.mx/jdperez/documentos/IJCSNS-WSN-publicado-03-2007.pdf>. (http://campus.cva.itesm.mx/jdperez/documentos/IJCSNS-WSN-publicado-03-2007.pdf)

ILIE-ABLACHIM, D.; PaTRU, G. C.; FLOREA, I. M.; ROSNER, D. Monitoring device ˇ for culture substrate growth parameters for precision agriculture: Acronym: MoniSen. Networking in Education and Research: RoEduNet International Conference 15th Edition, RoEduNet 2016 - Proceedings, IEEE, 2016.

INC, M. T. PIC16(L)F18426/46. 2017. 757 p.

INTEGRATED, M. Water Temperature Sensor : DS18S20. Maxim Integrated, v. 92, p. 1–21, 2017.

JUAN, M. N. V.; FARUK, F. R.; QUEZADA, Y. M. Design and implementation of WSN for precision agriculture in white cabbage crops. Proceedings of the 2017 IEEE 24th International Congress on Electronics, Electrical Engineering and Computing, INTERCON 2017, 2017.

LI, C. H.; LAO, K. W.; TAM, K. W. A flooding warning system based on RFID tag array for energy facility. RFID-TA 2018 - 2018 IEEE International Conference on RFID Technology and Applications, IEEE, 2018.

LoRa Alliance Technical Commitee. Low-Power Long Range LoRa ® Technology Transceiver Module. 2017. Disponível em: <https://lora-alliance.org/resource-hub/lorawantm-specification-v11>. (https://lora-alliance.org/resource-hub/lorawantm-specification-v11)

MEERA, C. S.; SAIRAM, P. S.; SUNNY, S.; SINGH, R. A.; SINGH, R. K. Implementation of an incampus fire alarm system using zigbee. 2015 2nd International Conference on Computing for Sustainable Global Development (INDIACom), p. 732–737, 2015.

MICROCHIP. PICkit 3 User’s Guide. [S.l.: s.n.], 2013. ISBN 9781620770085.

Microchip Technology Inc. MPLAB ® X IDE User ’ s Guide. 2012.

PAN, G.; HE, J.; WU, Q.; FANG, R.; CAO, J.; LIAO, D. Automatic stabilization of Zigbee network. 2018 International Conference on Artificial Intelligence and Big Data, ICAIBD 2018, IEEE, p. 224–227, 2018.

PANASONIC. Panasonic NCR18650B Specifications. Sanyo Energy, 2012. 18650 p. Disponível em: <https://www.batteryspace.com/prod-specs/NCR18650B.pdf>.

PATHAK, S.; KUMAR, M.; MOHAN, A.; KUMAR, B. Energy Optimization
of ZigBee Based WBAN for Patient Monitoring. Procedia Computer Science, Elsevier Masson SAS, v. 70, p. 414–420, 2015. ISSN 18770509. Disponível em: <http://dx.doi.org/10.1016/j.procs.2015.10.055>.

PEREIRA, L. S.; OWEIS, T.; ZAIRI, A. Irrigation management under water scarcity. Agricultural Water Management, v. 57, n. 3, p. 175–206, 2002. ISSN 03783774.

SEMTECH. Sx1276/77/78/79 Wireless, Sensing & Timing Datasheet. n. March, 2015. ISSN 00224944.

TANIM, M. M. Z. How does passive RFID works, briefly explained. 2016.

Texas Instruments. LM2596 SIMPLE SWITCHER ® Power Converter 150-kHz 3-A Step-Down Voltage Regulator. 2016. 1–45 p. Disponível em: <http://www.ti.com/lit/ds/symlink/lm2596.pdf>. (http://www.ti.com/lit/ds/symlink/lm2596.pdf)

TIWARI, P.; SAXENA, V. P.; MISHRA, R. G.; BHAVSAR, D. Wireless Sensor Networks: Introduction, Advantages, Applications and Research Challenges. HCTL Open International Journal of Technology Innovations and Research ISBN, v. 14, 2015. Disponível em: <http://ijtir.hctl.org>.

TOMAR, A. Introduction to Zigbee Technology. Global Technology Centre, v. 1, n. July, p. 1–24, 2011.

WANG, C.; GEORGE, D.; GREEN, P. R. Development of plough-able RFID sensor network systems for precision agriculture. WiSNet 2014 - Proceedings: 2014 IEEE Topical Conference on Wireless Sensors and Sensor Networks, IEEE, 2014.

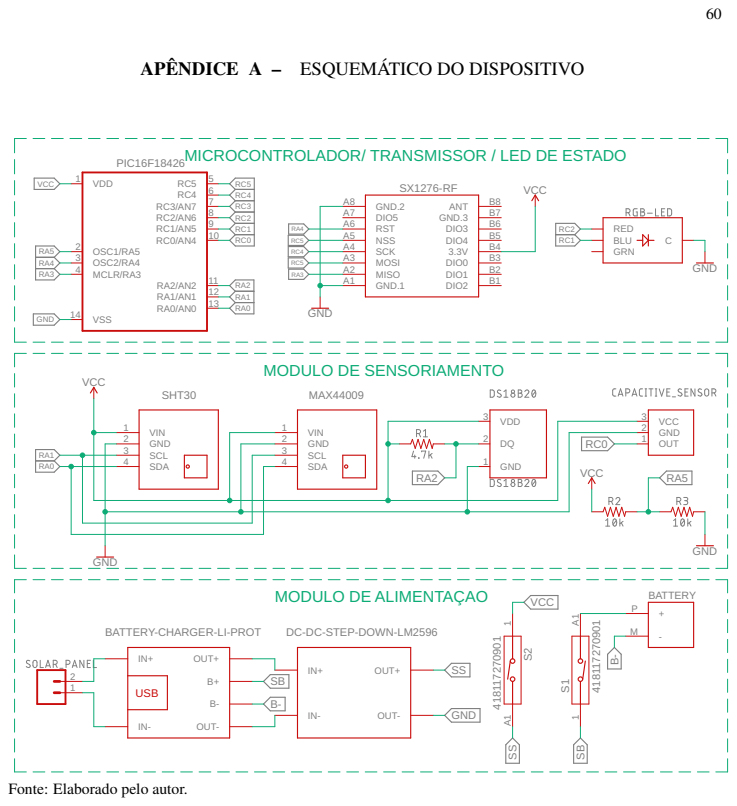
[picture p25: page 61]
BATTERY-CHARGER-LI-PROT; DC-DC-STEP-DOWN-LM2596; GND; VCC; OUT+ OUT-; B+B- OUT+ OUT- 1; GND.1 A1; MISO; MOSI A3; SCK; NSS; RST A6; DIO5 A7; GND.2 A8; ANT; B8 GND.3; B7 DIO3; B6 DIO4; B4 DIO0; B3 DIO1; B2 DIO2; BATTERY; MCLR/RA3; OSC1/RA5; 5 OSC2/RA4; VSS; VDD; PIC16F18426; OUT; 1 VIN; SCL; SDA; MAX44009 VIN; SHT30; GRN; BLU; RED; USB

APÊNDICE A – ESQUEMÁTICO DO DISPOSITIVO

MICROCONTROLADOR/ TRANSMISSOR / LED DE ESTADO

MODULO DE SENSORIAMENTO

MODULO DE ALIMENTAÇAO

Fonte: Elaborado pelo autor.

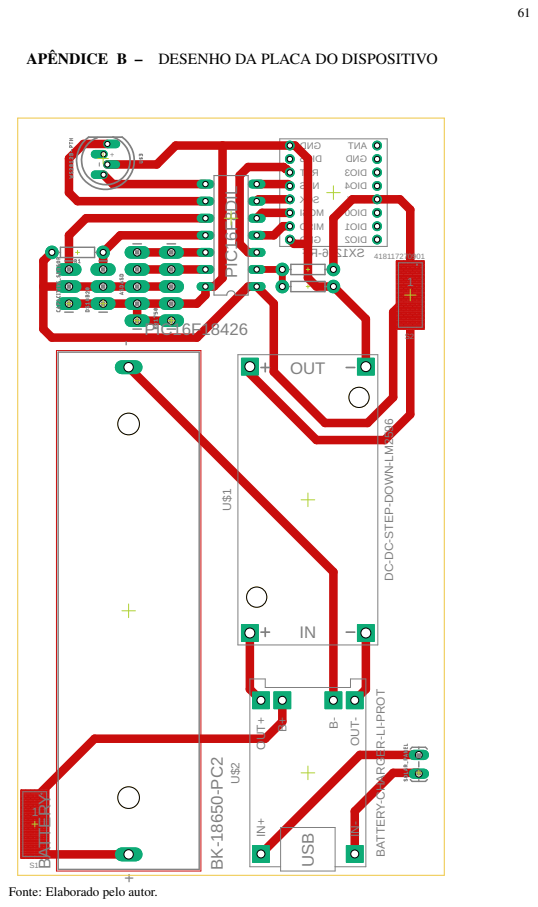
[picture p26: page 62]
OUT; B+B- USB; OUT+; OUT-; BATTERY; 418117270901 PIC¹⁶F8DIL

APÊNDICE B – DESENHO DA PLACA DO DISPOSITIVO

DC-DC-STEP-DOWN-LM2596 BATTERY-CHARGER-LI-PROT

Fonte: Elaborado pelo autor.

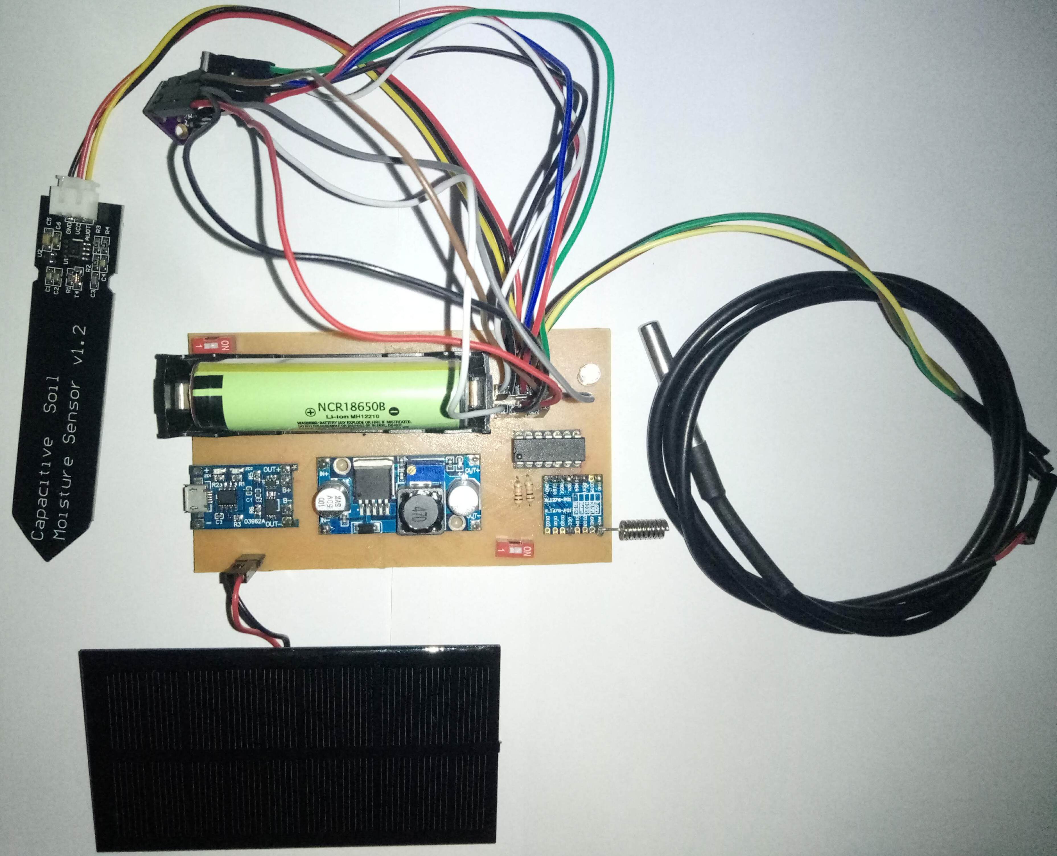
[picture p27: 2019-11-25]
documentation/Photos/placa_sensores.jpg

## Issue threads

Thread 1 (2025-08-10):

How do you control charging the Li battery with the solar panel?

HKPhysicist, 2025-08-10:
Hello Friend,
I am also a Microchip PIC fans.
I just came across your project and find that it is very nice.  You have add many new device drivers for the PIC 8 bit community.  Thank you very much.

There is one point which I do not understand.
How do you control charging the Li battery with the solar panel?  There seems no charger controller in your project.

Yours faithfully,
Timmy

emanuel36, 2025-08-11:
It is not SW controlled, the battery is connected to the solar panel using a charging module and a voltage regulator.

The answer to this question is on [schematic](https://github.com/emanuel36/LoRa-sensor-node-device/blob/master/documentation/Hardware/esquematico.png).

Closing this since it is not an issue.

Closed 2025-08-11.

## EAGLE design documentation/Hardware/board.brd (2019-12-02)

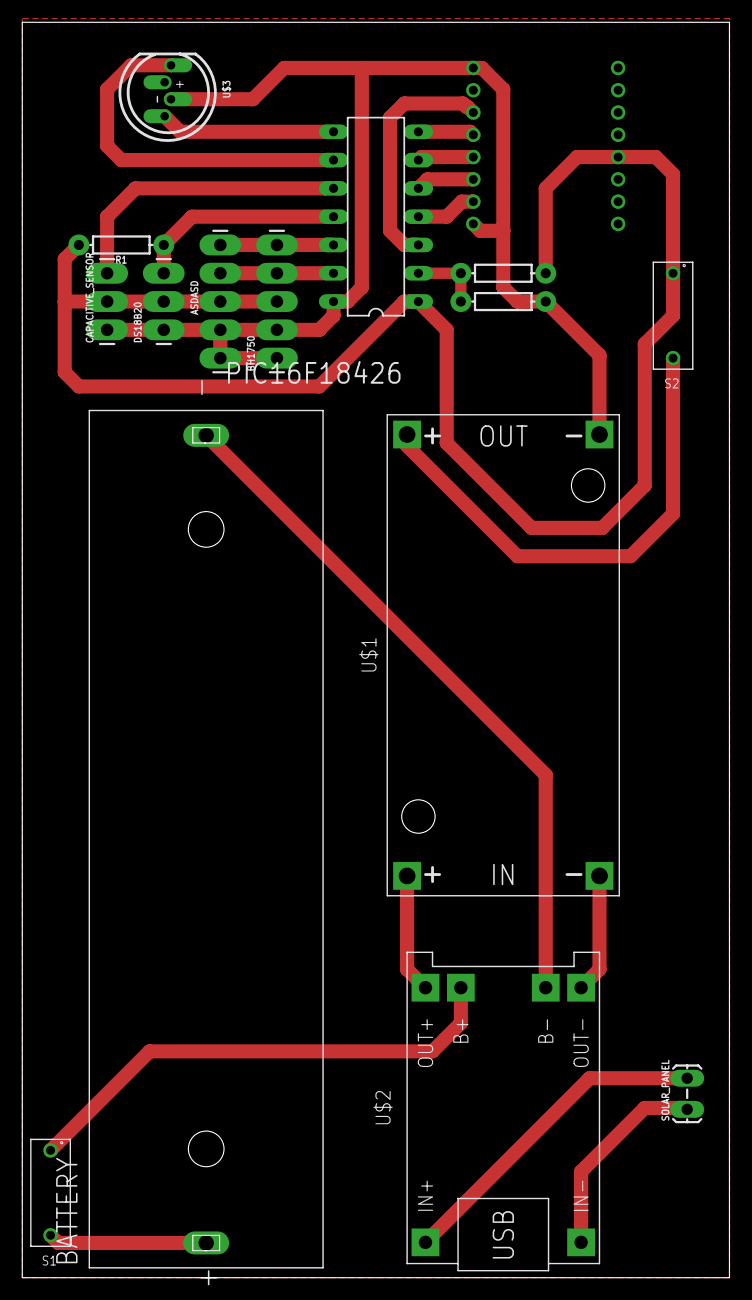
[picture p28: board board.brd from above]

Board: 2 copper layers, 63.5 x 112.7 mm, 16 parts (1 on the bottom side), 22 nets.

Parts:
ASDASD: 1X05_LONGPADS
BATTERY: BK-18650-PC2; MPD_BK-18650-PC2
BH1750: 1X05_LONGPADS
CAPACITIVE_SENSOR: 1X03_LONGPADS
DS18B20: 1X03_LONGPADS
PIC16F18426: PIC16F8DIL; DIL14
R1: 1k; AXIAL-0.3
R2, R3: 1M; AXIAL-0.3
S1, S2: 418117270901
SOLAR_PANEL: 1X02_LOCK_LONGPADS
SX1276-RF: WIRELESS-LORA-RFM95W#THT
U$1: DC-DC-STEP-DOWN-LM2596
U$2: BATTERY-CHARGER-LI-PROT
U$3: WS2812B-PTH; WS2812B-PTH-KIT

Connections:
B-: BATTERY.M, U$2.B-
GND: ASDASD.1, ASDASD.2, BH1750.1, BH1750.2, CAPACITIVE_SENSOR.1, DS18B20.1, PIC16F18426.14, R3.P$2, SX1276-RF.A1, SX1276-RF.A8, U$1.OUT-, U$3.2
unnamed: U$1.IN+, U$2.OUT+
unnamed: SOLAR_PANEL.1, U$2.IN-
unnamed: BATTERY.P, S1.A1
unnamed: U$1.IN-, U$2.OUT-
unnamed: SOLAR_PANEL.2, U$2.IN+
RA0: ASDASD.4, BH1750.4, PIC16F18426.13
RA1: ASDASD.5, BH1750.5, PIC16F18426.12
RA2: DS18B20.3, PIC16F18426.11, R1.P$1
RA3: PIC16F18426.4, SX1276-RF.A2
RA4: PIC16F18426.3, SX1276-RF.A6
RA5: PIC16F18426.2, R2.P$1, R3.P$1
RC0: CAPACITIVE_SENSOR.3, PIC16F18426.10
RC1: PIC16F18426.9, U$3.4
RC2: PIC16F18426.8, U$3.1
RC3: PIC16F18426.7, SX1276-RF.A5
RC4: PIC16F18426.6, SX1276-RF.A4
RC5: PIC16F18426.5, SX1276-RF.A3
SB: S1.1, U$2.B+
SS: S2.A1, U$1.OUT+
VCC: ASDASD.3, BH1750.3, CAPACITIVE_SENSOR.2, DS18B20.2, PIC16F18426.1, R1.P$2, R2.P$2, S2.1, SX1276-RF.B4

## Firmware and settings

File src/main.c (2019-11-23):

#include <xc.h>
#include <stdio.h>
#include <stdlib.h>
#include <stdint.h>
#include "main.h"
#include "mcu.h"
#include "supplyVoltage.h"
#include "sht30.h"
#include "max44009.h"
#include "ds18b20.h"
#include "soilMoistureSensor.h"
#include "sx1276.h"

char packet[30]; 
float supplyVoltage, 
      soilTemperature, 
      soilMoistureLevel,
      airTemperature, 
      airHumidity, 
      lightness;

void setSystemStatus(bool state){
    systemStatus = state;
}

bool getSystemStatus(){
    return systemStatus;
}

void variablesReset(){
    supplyVoltage = 0.0;
    soilTemperature = 0.0;
    airTemperature = 0.0;
    airHumidity = 0.0;
    lightness = -1.0;
    soilMoistureLevel = 0;
}

bool lightnessCheck(){
    if(lightness > 189000.0 || lightness < 0.0)                         return false;
    return true;
}

bool temperatureCheck(){
    if(airTemperature > 80.0 || airTemperature < 0.1)                return false;
    if(soilTemperature > 80.0 || soilTemperature < 0.1)              return false;
    return true;
}

bool humidityCheck(){
    if(airHumidity > 100.0 || airHumidity < 0.1)                     return false;
    return true;
}

bool dataCheck(){
    if(temperatureCheck() && humidityCheck() && lightnessCheck())     return true;
    return false;
}

bool voltageCheck(){
    if(supplyVoltage < 2.5 || supplyVoltage > 3.5)                  return false;
    return true;
}

bool systemCheck(){
    if(dataCheck() && voltageCheck()){
        setSystemStatus(NORMAL);
    }else{
        setSystemStatus(WARNING);
    }
}

void sensorsRead(){
    variablesReset();
    getSupplyVoltage(&supplyVoltage);
    SHT30Read(&airTemperature, &airHumidity);
    max44009Read(&lightness);
    ds18b20Read(&soilTemperature);
    soilMoistureSensorRead(&soilMoistureLevel);
}

void pktBuild(){
    packet[0] = '\0';
    sprintf(packet, "%d|%.3f|%.2f|%.2f|%.2f|%.1f|%.1f", getSystemStatus(), supplyVoltage, airTemperature, soilTemperature, airHumidity, soilMoistureLevel, lightness);
}

void SX1276Transmit(){
    while(beginPacket(false) == 0){
        setSystemStatus(WARNING);
        __delay_ms(250);
    }
    
    beginPacket(false);
    SX1276WriteString(packet);
    endPacket(false);
}

void callBack(){
    sensorsRead();
    systemCheck();
    pktBuild();
    SX1276Transmit();
}

void main(void){
    SYSTEM_Initialize();
    while(1){
        SLEEP();
    }
}

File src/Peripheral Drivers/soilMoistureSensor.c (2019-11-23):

#include <xc.h>
#include "adc.h"
#include "soilMoistureSensor.h"
#include "supplyVoltage.h"

void soilMoistureSensorPinInicialize(){
    ANSC0 = 1;
    TRISC0 = 1;
}

void soilMoistureSensorRead(float *moisture){
    float supplyVoltage, sensorVoltage;
    uint16_t adcResult;
    int moistureLevel;
            
    getSupplyVoltage(&supplyVoltage);
    ADC_use_fvr(0);
    adcResult = ADC_GetSingleConversion(RC0_channel);
    ADC_use_fvr(1);
    sensorVoltage = (supplyVoltage * adcResult) / 4096.0;
    
    *moisture = (0.7 - (sensorVoltage/supplyVoltage)) * 100;   
    
    if(*moisture < 0.0)   *moisture = 0;
    if(*moisture > 30.0)  *moisture = 30;
}

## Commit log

2019-09-23 MCC config - Led Blink
2019-09-24 UART for debug
2019-09-24 i2c - mssp1
2019-09-24 sht30 driver
2019-09-24 sht30 driver error detection
    [sht30.c]
2019-09-24 max44009 lightness sensor driver
2019-09-24 battery voltage monitor
2019-09-28 Timer0 Interrupt - 5 Minutes
2019-09-28 Handler Interrupt bug fix
    [main.c, mcc.c]
2019-09-29 Timer2 and Led Status
2019-09-30 i2c bug correction
2019-10-03 ADC bug fix
2019-10-08 sensors running together
2019-10-08 soil moisture capcitive sensor
2019-10-09 spi drivers
2019-10-13 spi bug fixed
2019-10-30 add board to readme.md
2019-10-31 board img update
2019-11-07 several adjusts specially in SPI protoco
2019-11-16 several changes for bluetooth version board
2019-11-23 soil moisture sensor calibrated
2019-11-25 Board photos
2019-12-02 new files
    [board.brd, schematic.sch]

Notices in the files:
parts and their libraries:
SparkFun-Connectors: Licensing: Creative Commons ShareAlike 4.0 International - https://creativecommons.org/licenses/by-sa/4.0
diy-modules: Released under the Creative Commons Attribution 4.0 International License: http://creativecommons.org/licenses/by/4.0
